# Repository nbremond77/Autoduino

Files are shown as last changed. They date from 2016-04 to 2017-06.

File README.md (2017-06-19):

# Autoduino

Arduino UNO shield to interface the I/O modules of A4 Technology // Autoduino est un bouclier pour Arduino Uno qui permet de piloter les maquettes A4 Technology utilisées pour l'enseignement de la technologie.

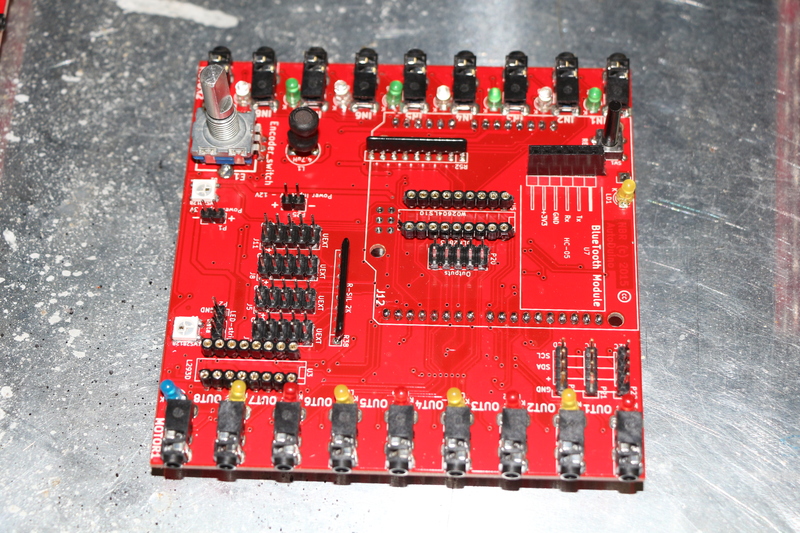
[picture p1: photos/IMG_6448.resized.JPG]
alt textAutoduino Shield


Exemples de maquettes:

http://www.a4.fr/maquette-motorisee-programmable-portail-1-battant-version-kit.html

http://www.a4.fr/banc-d-essai-eclairage-domestique-autolumi-version-kit.html

http://www.a4.fr/autoalarme-maquette-experimentale-d-un-systeme-d-alarme-kit.html

Vous trouverez sur ce site, les fichiers relatif à la carte électronique, et les développements logiciels associés.

# Introduction
Le bouclier Autoduino permet de piloter les maquettes A4 technology grâce à un Arduino UNO. Pour cela, le bouclier est équipé de 
- 16 connecteurs Jack 2.5mm permettant la connection des capteurs et actionneurs de la maquette, équipé de LED pour indiquer l'état de l'entrée ou de la sortie.
- 2 connecteurs jack 2.5mm pour deux moteurs DC,
- 2 LED RGB adressables (type WS2812B),
- 1 encodeur/push,
- quelques connecteurs supplémentaires permettant de connecter des capteurs/actionneurs plus évolués UEXT (I2C, SPI, Serial...) ou I2C pour un écran LCD (non testé) par exemple,
- 1 connecteur pour un module BlueTooth,
- 1 convertisseur Step/Up permettant d'alimenter la carte et l'Arduino avec deux piles de 1.5V, ou avec un accumulateur 3.7V.

Pour supporter le grand nombre d'entrées/sorties, il a été nécessaire d'utiliser un GPIO Expander (PCA9555). Celà implique l'utilisation d'une bibliothèque logiciel adaptée.
La programmation de l'Arduino peut se faire grâce à blockly@rDuino: http://technologiescollege.github.io/ qui inclus maintenant la bibliothèque adéquate.

A noter: Autoduino utilise des composants CMS et des composants traversants. Le cuircuit imprimé fait 100x100mm et est du type double-face.

# Note importante
Une nouvelle version de cet Autoduino est en préparation. La carte électronique sera plus simple (moins de connecteurs), et surtout, elle sera adaptée à un Arduino Due qui dispose de beaucoup plus d'entrées/sortie. Cela permettra d'éviter l'utilisation du GPIO Explander (PCA9555), ce qui simplifie grandement le logiciel.
De plus, l'Arduino Due fonctionne en 3.3V, ce qui simplifie l'utilisation de périphériques récents (Ecran tactile LCD...). Les moteurs resteront connectés au 5V.
Enfin, c'est un processeur 32 bits beaucoup plus performant que celui de l'Arduino Uno;

De plus, j'ai prévu quelques amélioration:
- Ajout de connecteurs Grove en plus des connecteurs jack 2.5mm, pour permettre une utilisation beaucoup plus polyvalente,
- Possibilité de connecter le module Bluetooth sur un RX/TX différent de celui connecté à l'USB,
- Ajouter une interface permettant de connecter un écran tactile LCD de 2.8 pouces.

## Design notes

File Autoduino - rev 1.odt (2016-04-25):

Autoduino

# Description

Autoduino est un module (carte électronique et boîtier) développé pour piloter les maquettes didactiques de type alarme de maison, éclairage, portail, etc.

Ce module basé sur un Arduino peut être programmé par l'enseignant ou les élèves, soit dans un environnement de développement utilisant un langage proche du langage C, soir graphiquement dans Drakon (programme multi-plateforme de programmation graphique).

Ce module Autoduino se connecte à des petites cartes d'interface (entrée bouton poussoir, télécommande infra rouge, contact fin de course, … et sorties Led, moteur, buzzer, …) qui sont situées sur les maquettes que l'on souhaite animer.

# Autres modules disponibles sur le marché

L'Autoduino est équivalent aux modules suivants de la société A4 technologie :

- Autoprog (environ 180 Euros monté, 100 Euros en kit)
- Autoprog Uno (environ 230 Euros monté)

Par rapport à ces modules, on note les avantages suivants :

- Moins cher si les achats sont optimisés (environ 70 Euros de composants si réalisés en 10 exemplaires),
- Équipe en standard d'un écran LCD et d'un bouton rotatif ce qui facilite le débogage des programmes,
- Équipé d'une interface moteur intégrée,
- Equipé d'une interface radio de type Bluetooth permettant à plusieurs module de dialoguer entre eux,
- Basé sur un Arduino (architecture/carte très connue est appréciée dans le milieu éducatif, facile à programmer) qui dispose d'une puissance de calcul très supérieure au PicAxe qui équipe l'Autoprog. L'Autoprog Uno est quant à lui équipé d'un Arduino.
- Compatible avec d'autres carte à micro-contrôleurs, par exemple STM32/Nucleo qui dispose d'un micro-contrôleur 32 bits tournant à 100MHz offrant ainsi une puissance de calcul sans commune mesure.

# Applications

Les applications envisagées sont les suivantes :

- Pilotage des maquettes A4 Technologie : Alarme maison, éclairage maison, portail, plate-forme élévatrice…
- Pilotage de mini-robots, ou de véhicules télécommandés ou autonomes,
- Système de mesure automatisée pour le laboratoire de physique.

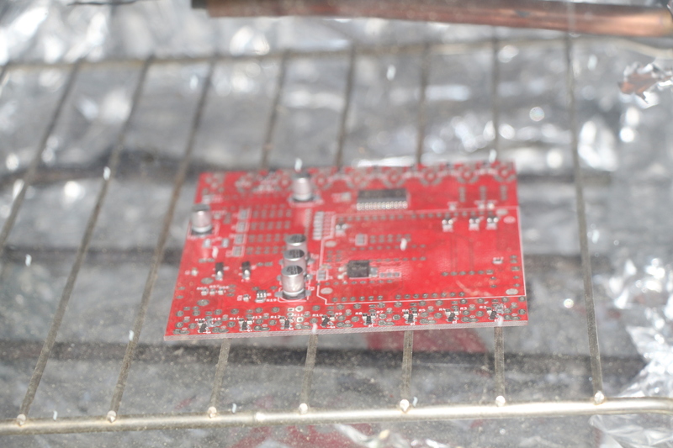
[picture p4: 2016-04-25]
photos/IMG_6421.resized.JPG

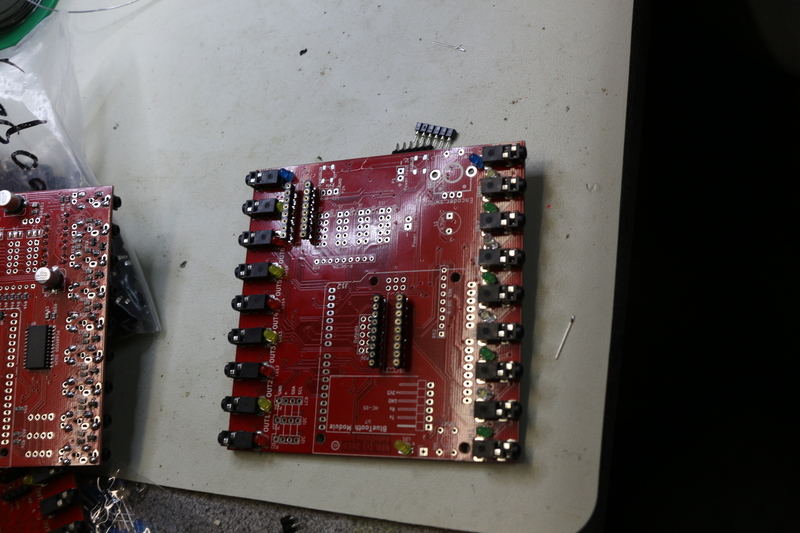
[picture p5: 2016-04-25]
photos/IMG_6434.resized.JPG

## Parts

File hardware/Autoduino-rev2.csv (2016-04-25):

Reference | Value | Footprint | Datasheet
SW1 | Push1 | FreeTtronics:SW_PUSHBUTTON_PTH
J3 | UEXT | Pin_Headers:Pin_Header_Straight_2x05
J5 | UEXT | Pin_Headers:Pin_Header_Straight_2x05
J12 | Nucleo/Arduino Board header | FreeTtronics:ARDUINO_SHIELD
U2 | MCP1640t-i/chy | w_smd_trans:sot23-6
C4 | 220uF/16V | Capacitors_SMD:c_elec_8x10
C2 | 220uF/16V | Capacitors_SMD:c_elec_8x10
R19 | 976k 1% | Resistors_SMD:R_0805
R20 | 309k 1% | Resistors_SMD:R_0805
L1 | 4.7uH | Inductors:INDUCTOR_V
J2 | V_select | br_pretty:Select
J4 | V_select | br_pretty:Select
U6 | 24xx512 EEPROM - NC | w_smd_dil:so-8
P1 | Power Input 3V | Pin_Headers:Pin_Header_Straight_1x02
R52 | R-SIL 10K | Discret:r_pack8
J8 | UEXT | Pin_Headers:Pin_Header_Straight_2x05
J6 | V_select | br_pretty:Select
U5 | ULN2803 - NC | Sockets_DIP:DIP-18__300
P20 | Outputs - NC | Pin_Headers:Pin_Header_Straight_2x05
Q18 | BSS138 | FreeTtronics:SOT23_FET
LD2 | LED Green | LEDs:LED-3MM
U4 | PCA9555D SO24 | Housings_SOIC:SOIC-24_7.5x15.4mm_Pitch1.27mm
P23 | LCD | Pin_Headers:Pin_Header_Straight_1x04
D1 | DIODE | Diodes_SMD:Diode-MiniMELF_Handsoldering
E1 | Encoder_switch | w_misc_comp:encoder_alps-ec12d
C9 | 100n | Capacitors_SMD:C_0805
C10 | 100n | Capacitors_SMD:C_0805
U3 | L293D | Sockets_DIP:DIP-16__300
D2 | WS2812B | FreeTtronics:WS2812B
D3 | WS2812B | FreeTtronics:WS2812B
U7 | HC-05 | Pin_Headers:Pin_Header_Angled_1x06
R1 | 1k | Resistors_SMD:R_0805
C8 | 220uF/16V | Capacitors_SMD:c_elec_8x10
J1 | V_select | br_pretty:Select
Q19 | BSS138 | FreeTtronics:SOT23_FET
Q20 | BSS138 | FreeTtronics:SOT23_FET
R59 | 220R | Resistors_SMD:R_0805
P24 | LED-strip | Pin_Headers:Pin_Header_Straight_1x03
C11 | 220uF/16V | Capacitors_SMD:c_elec_8x10
Q1 | BSS138 | FreeTtronics:SOT23_FET
R44 | 1k | Resistors_SMD:R_0805
R45 | 1k | Resistors_SMD:R_0805
R46 | 1k | Resistors_SMD:R_0805
R57 | 10k | Resistors_SMD:R_0805
R58 | 10k | Resistors_SMD:R_0805
R60 | 10k | Resistors_SMD:R_0805
R47 | 1k | Resistors_SMD:R_0805
R48 | 1k | Resistors_SMD:R_0805
C6 | 100n | Capacitors_SMD:C_0805
U1 | LD29150DT33R | FreeTtronics:DPAK
C3 | 220uF/16V | Capacitors_SMD:c_elec_8x10
C1 | 100n | Capacitors_SMD:C_0805
J11 | UEXT | Pin_Headers:Pin_Header_Straight_2x05
J10 | V_select | br_pretty:Select
R49 | 1k | Resistors_SMD:R_0805
R50 | 1k | Resistors_SMD:R_0805
R56 | 1k | Resistors_SMD:R_0805
R17 | 220R | Resistors_SMD:R_0805
LD1 | LED Yellow | LEDs:LED-3MM
P22 | I2C | Pin_Headers:Pin_Header_Straight_1x04
P21 | I2C | Pin_Headers:Pin_Header_Straight_1x04
J7 | V_select | br_pretty:Select
R38 | R-SIL 2K | Discret:r_pack8
R41 | 10k | Resistors_SMD:R_0805
R42 | 10k | Resistors_SMD:R_0805
R43 | 10k | Resistors_SMD:R_0805
R53 | 10k | Resistors_SMD:R_0805
R54 | 10k | Resistors_SMD:R_0805
R55 | 10k | Resistors_SMD:R_0805
R37 | 1k | Resistors_SMD:R_0805
R39 | 1k | Resistors_SMD:R_0805
LD18 | LED Yellow | LEDs:LED-3MM
LD19 | LED Yellow | LEDs:LED-3MM
J9 | V_select | br_pretty:Select
Q17 | BSS138 | FreeTtronics:SOT23_FET
R51 | 10k | Resistors_SMD:R_0805
R40 | 10k | Resistors_SMD:R_0805
P9 | IN8 | pretty:PC-208B-Jack2.5_Stereo
LD10 | LED Red | LEDs:LED-3MM
R21 | 1k | Resistors_SMD:R_0805
Q9 | BSS138 | FreeTtronics:SOT23_FET
P17 | OUT8 | pretty:PC-208B-Jack2.5_Stereo
LD3 | LED Green | LEDs:LED-3MM
R3 | 1k | Resistors_SMD:R_0805
Q2 | BSS138 | FreeTtronics:SOT23_FET
P2 | IN1 | pretty:PC-208B-Jack2.5_Stereo
LD11 | LED Red | LEDs:LED-3MM
R23 | 1k | Resistors_SMD:R_0805
Q10 | BSS138 | FreeTtronics:SOT23_FET
P10 | OUT1 | pretty:PC-208B-Jack2.5_Stereo
LD4 | LED Green | LEDs:LED-3MM
R5 | 1k | Resistors_SMD:R_0805
Q3 | BSS138 | FreeTtronics:SOT23_FET
P3 | IN2 | pretty:PC-208B-Jack2.5_Stereo
LD12 | LED Red | LEDs:LED-3MM
R25 | 1k | Resistors_SMD:R_0805
Q11 | BSS138 | FreeTtronics:SOT23_FET
P11 | OUT2 | pretty:PC-208B-Jack2.5_Stereo
LD5 | LED Green | LEDs:LED-3MM
R7 | 1k | Resistors_SMD:R_0805
Q4 | BSS138 | FreeTtronics:SOT23_FET
P4 | IN3 | pretty:PC-208B-Jack2.5_Stereo
LD13 | LED Red | LEDs:LED-3MM
R27 | 1k | Resistors_SMD:R_0805
Q12 | BSS138 | FreeTtronics:SOT23_FET
P12 | OUT3 | pretty:PC-208B-Jack2.5_Stereo
LD6 | LED Green | LEDs:LED-3MM
R9 | 1k | Resistors_SMD:R_0805
Q5 | BSS138 | FreeTtronics:SOT23_FET
P5 | IN4 | pretty:PC-208B-Jack2.5_Stereo
LD14 | LED Red | LEDs:LED-3MM
R29 | 1k | Resistors_SMD:R_0805
Q13 | BSS138 | FreeTtronics:SOT23_FET
P13 | OUT4 | pretty:PC-208B-Jack2.5_Stereo
LD7 | LED Green | LEDs:LED-3MM
R11 | 1k | Resistors_SMD:R_0805
Q6 | BSS138 | FreeTtronics:SOT23_FET
P6 | IN5 | pretty:PC-208B-Jack2.5_Stereo
LD15 | LED Red | LEDs:LED-3MM
R31 | 1k | Resistors_SMD:R_0805
Q14 | BSS138 | FreeTtronics:SOT23_FET
P14 | OUT5 | pretty:PC-208B-Jack2.5_Stereo
LD8 | LED Green | LEDs:LED-3MM
R13 | 1k | Resistors_SMD:R_0805
Q7 | BSS138 | FreeTtronics:SOT23_FET
P7 | IN6 | pretty:PC-208B-Jack2.5_Stereo
LD16 | LED Red | LEDs:LED-3MM
R33 | 1k | Resistors_SMD:R_0805
Q15 | BSS138 | FreeTtronics:SOT23_FET
P15 | OUT6 | pretty:PC-208B-Jack2.5_Stereo
LD9 | LED Green | LEDs:LED-3MM
R15 | 1k | Resistors_SMD:R_0805
Q8 | BSS138 | FreeTtronics:SOT23_FET
P8 | IN7 | pretty:PC-208B-Jack2.5_Stereo
LD17 | LED Red | LEDs:LED-3MM
R35 | 1k | Resistors_SMD:R_0805
Q16 | BSS138 | FreeTtronics:SOT23_FET
P16 | OUT7 | pretty:PC-208B-Jack2.5_Stereo
P18 | MOTOR1 | pretty:PC-208B-Jack2.5_Stereo
P19 | MOTOR2 | pretty:PC-208B-Jack2.5_Stereo
P25 | Power Input 7V - 12V | Pin_Headers:Pin_Header_Straight_1x02
D4 | DIODE | Diodes_SMD:Diode-MiniMELF_Handsoldering
R2 | 220R | Resistors_SMD:R_0805
R4 | 220R | Resistors_SMD:R_0805
R6 | 220R | Resistors_SMD:R_0805
R8 | 220R | Resistors_SMD:R_0805
R10 | 220R | Resistors_SMD:R_0805
R12 | 220R | Resistors_SMD:R_0805
R14 | 220R | Resistors_SMD:R_0805
R16 | 220R | Resistors_SMD:R_0805
R34 | 220R | Resistors_SMD:R_0805
R32 | 220R | Resistors_SMD:R_0805
R30 | 220R | Resistors_SMD:R_0805
R28 | 220R | Resistors_SMD:R_0805
R26 | 220R | Resistors_SMD:R_0805
R24 | 220R | Resistors_SMD:R_0805
R22 | 220R | Resistors_SMD:R_0805
R18 | 220R | Resistors_SMD:R_0805

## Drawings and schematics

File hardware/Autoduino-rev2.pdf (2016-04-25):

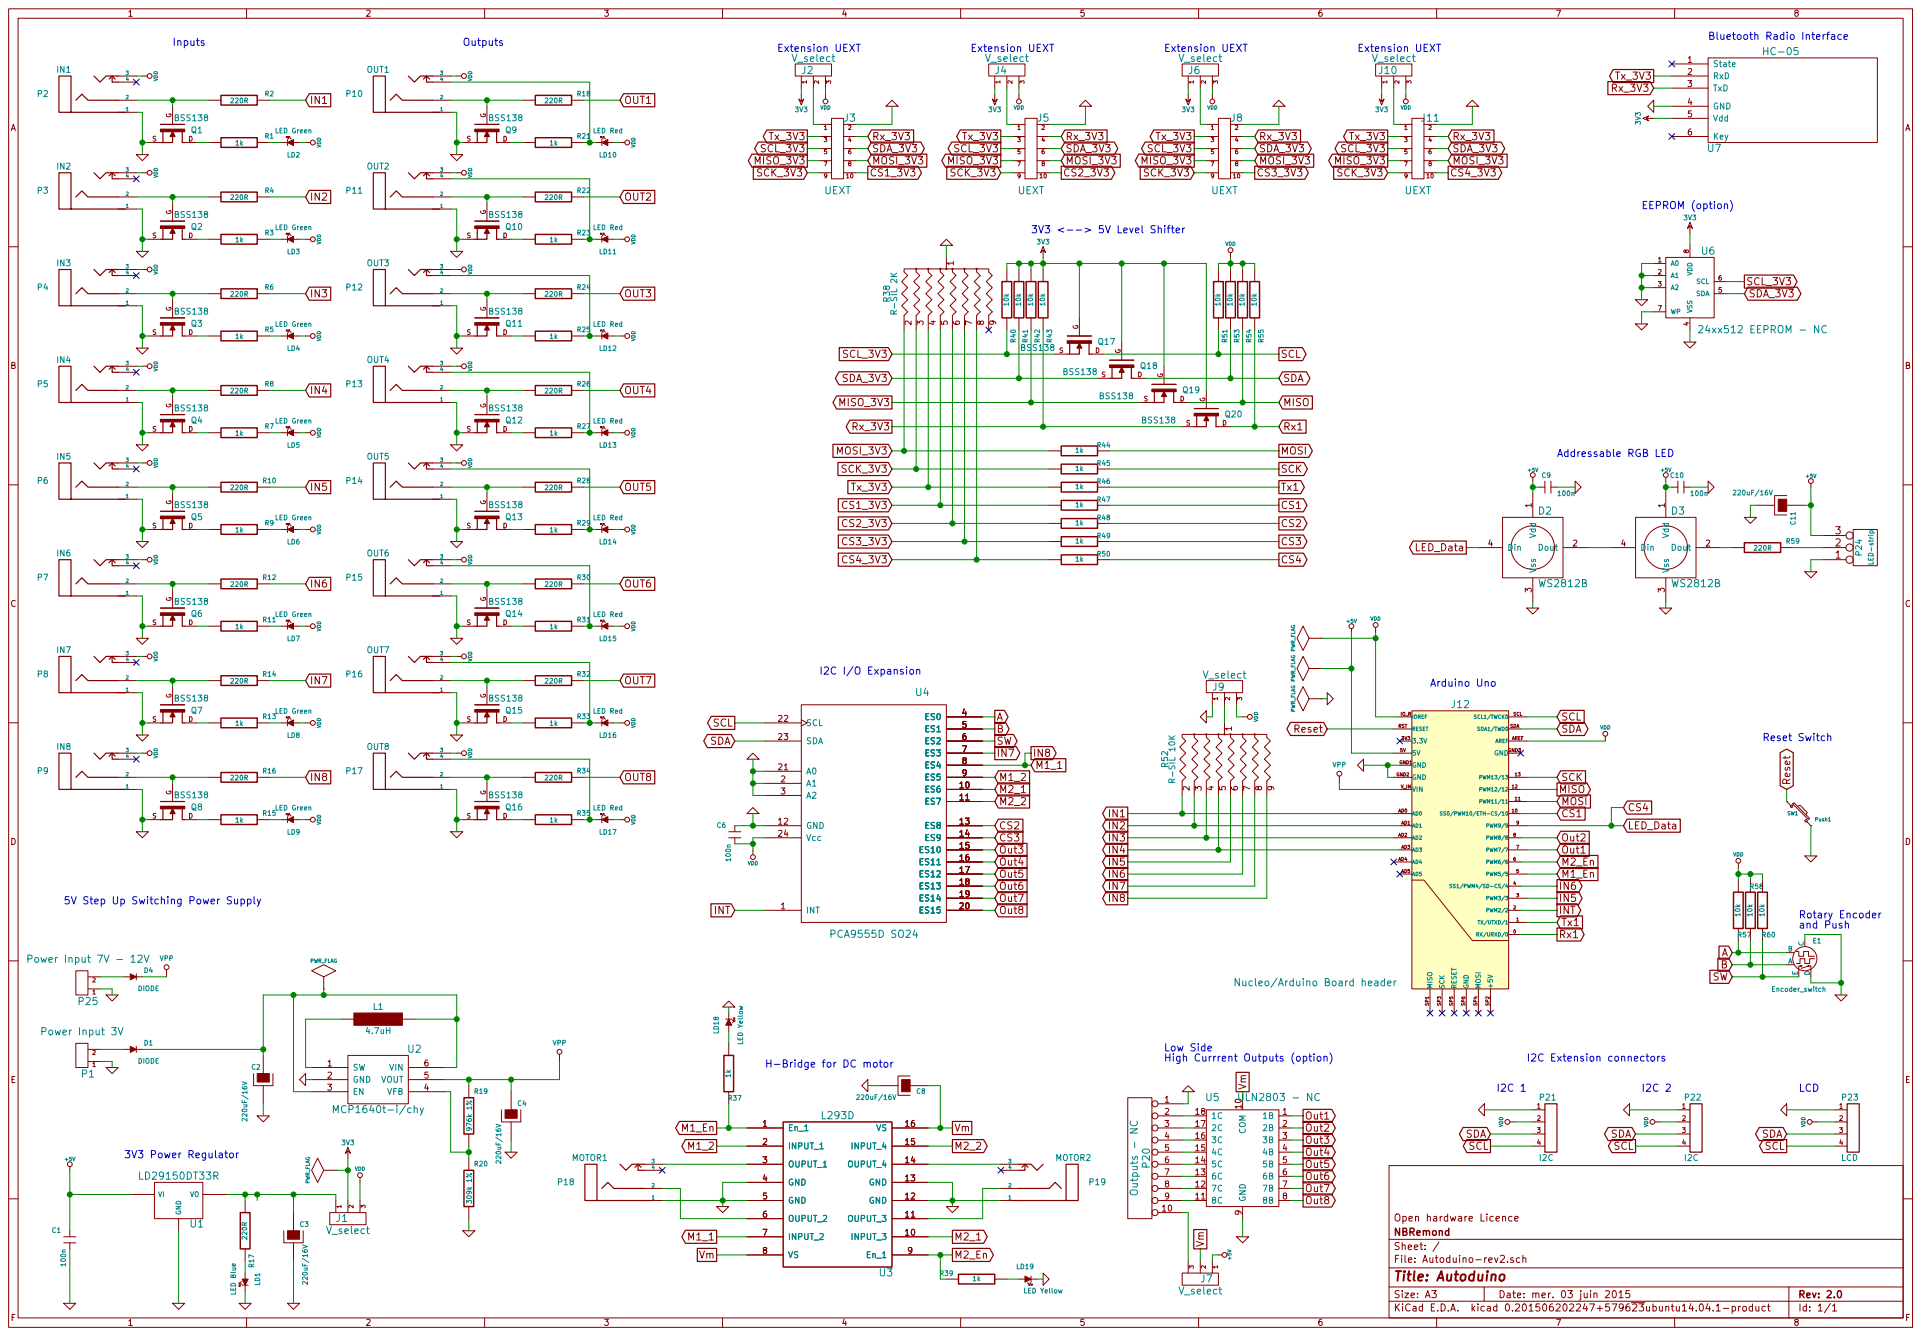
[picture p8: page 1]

1 Dout 2 Vss 3 Din 4 D2WS2812B Vdd

Rotary Encoder and Push Reset Switch

5V Step Up Switching Power Supply

Low Side
High Currrent Outputs (option)

H-Bridge for DC motor

File: Autoduino-rev2.sch Sheet: / NBRemond Open hardware Licence

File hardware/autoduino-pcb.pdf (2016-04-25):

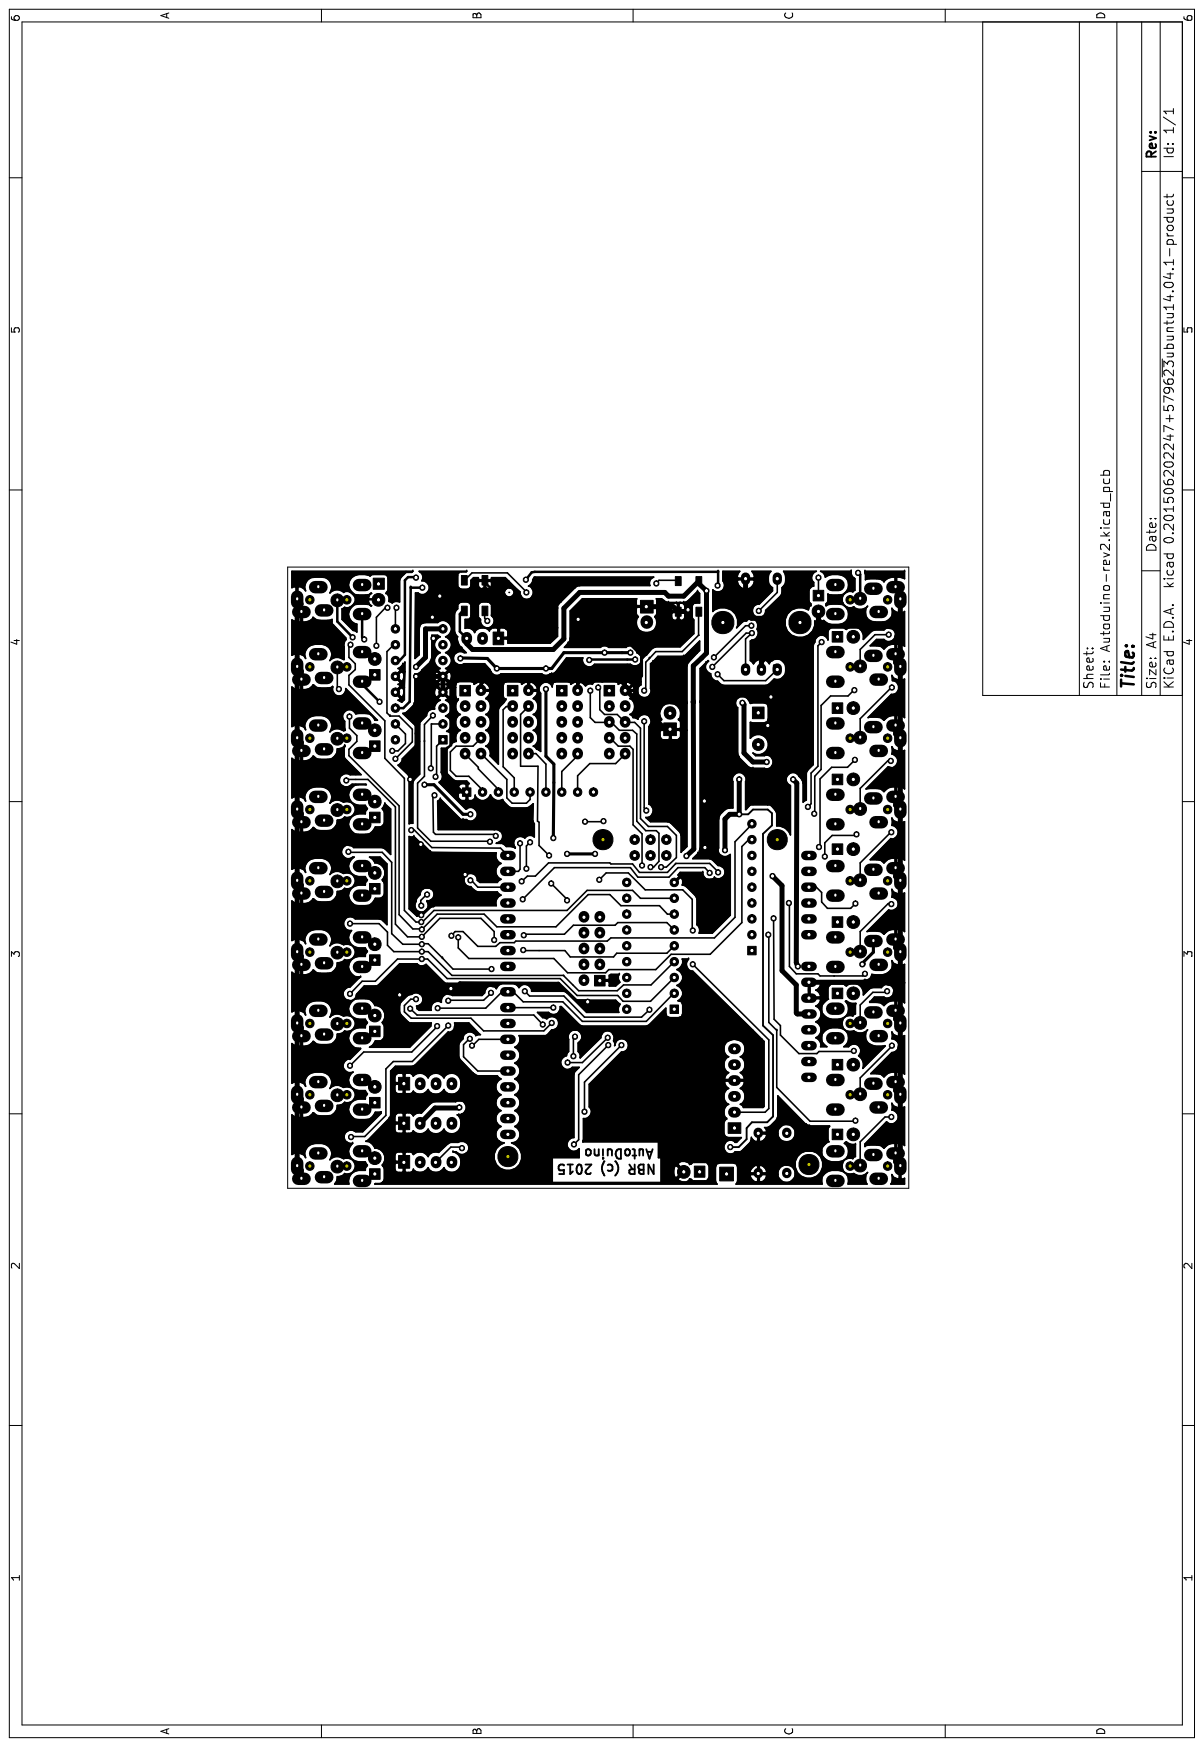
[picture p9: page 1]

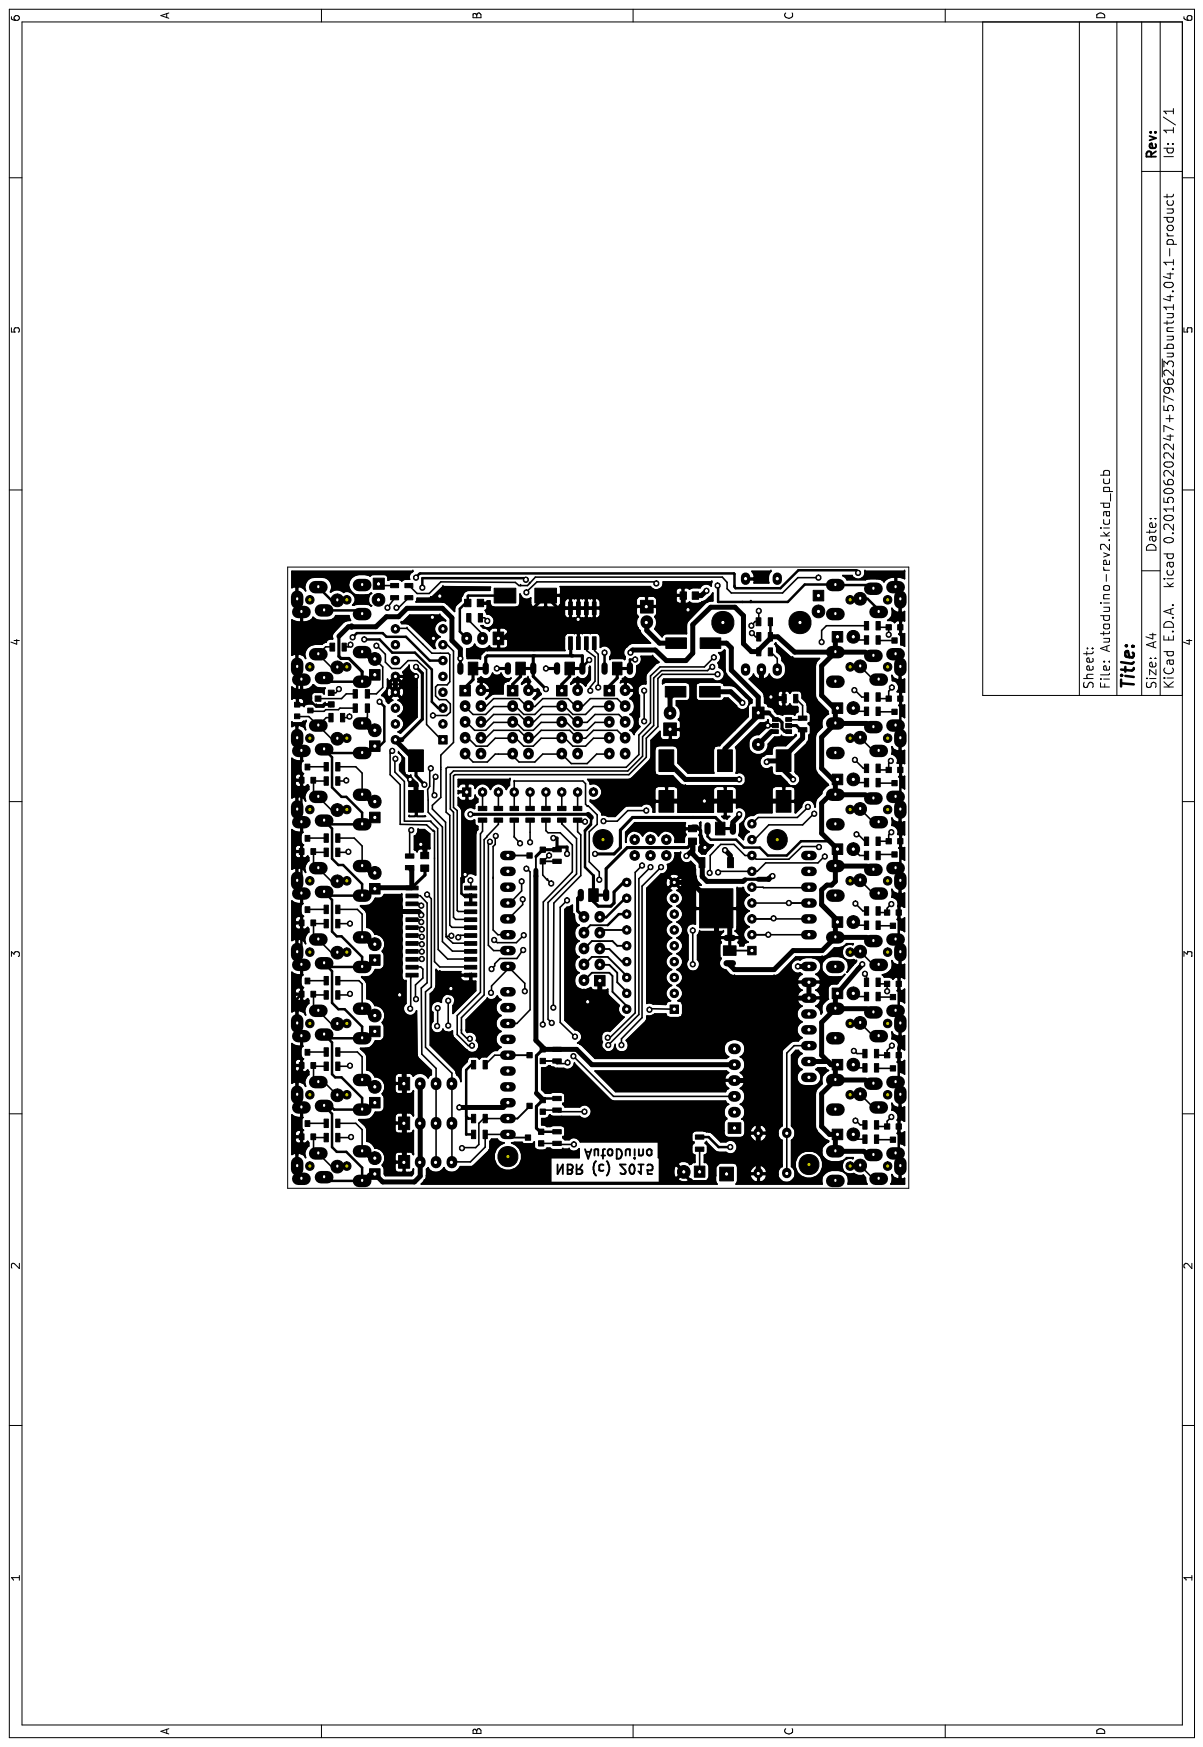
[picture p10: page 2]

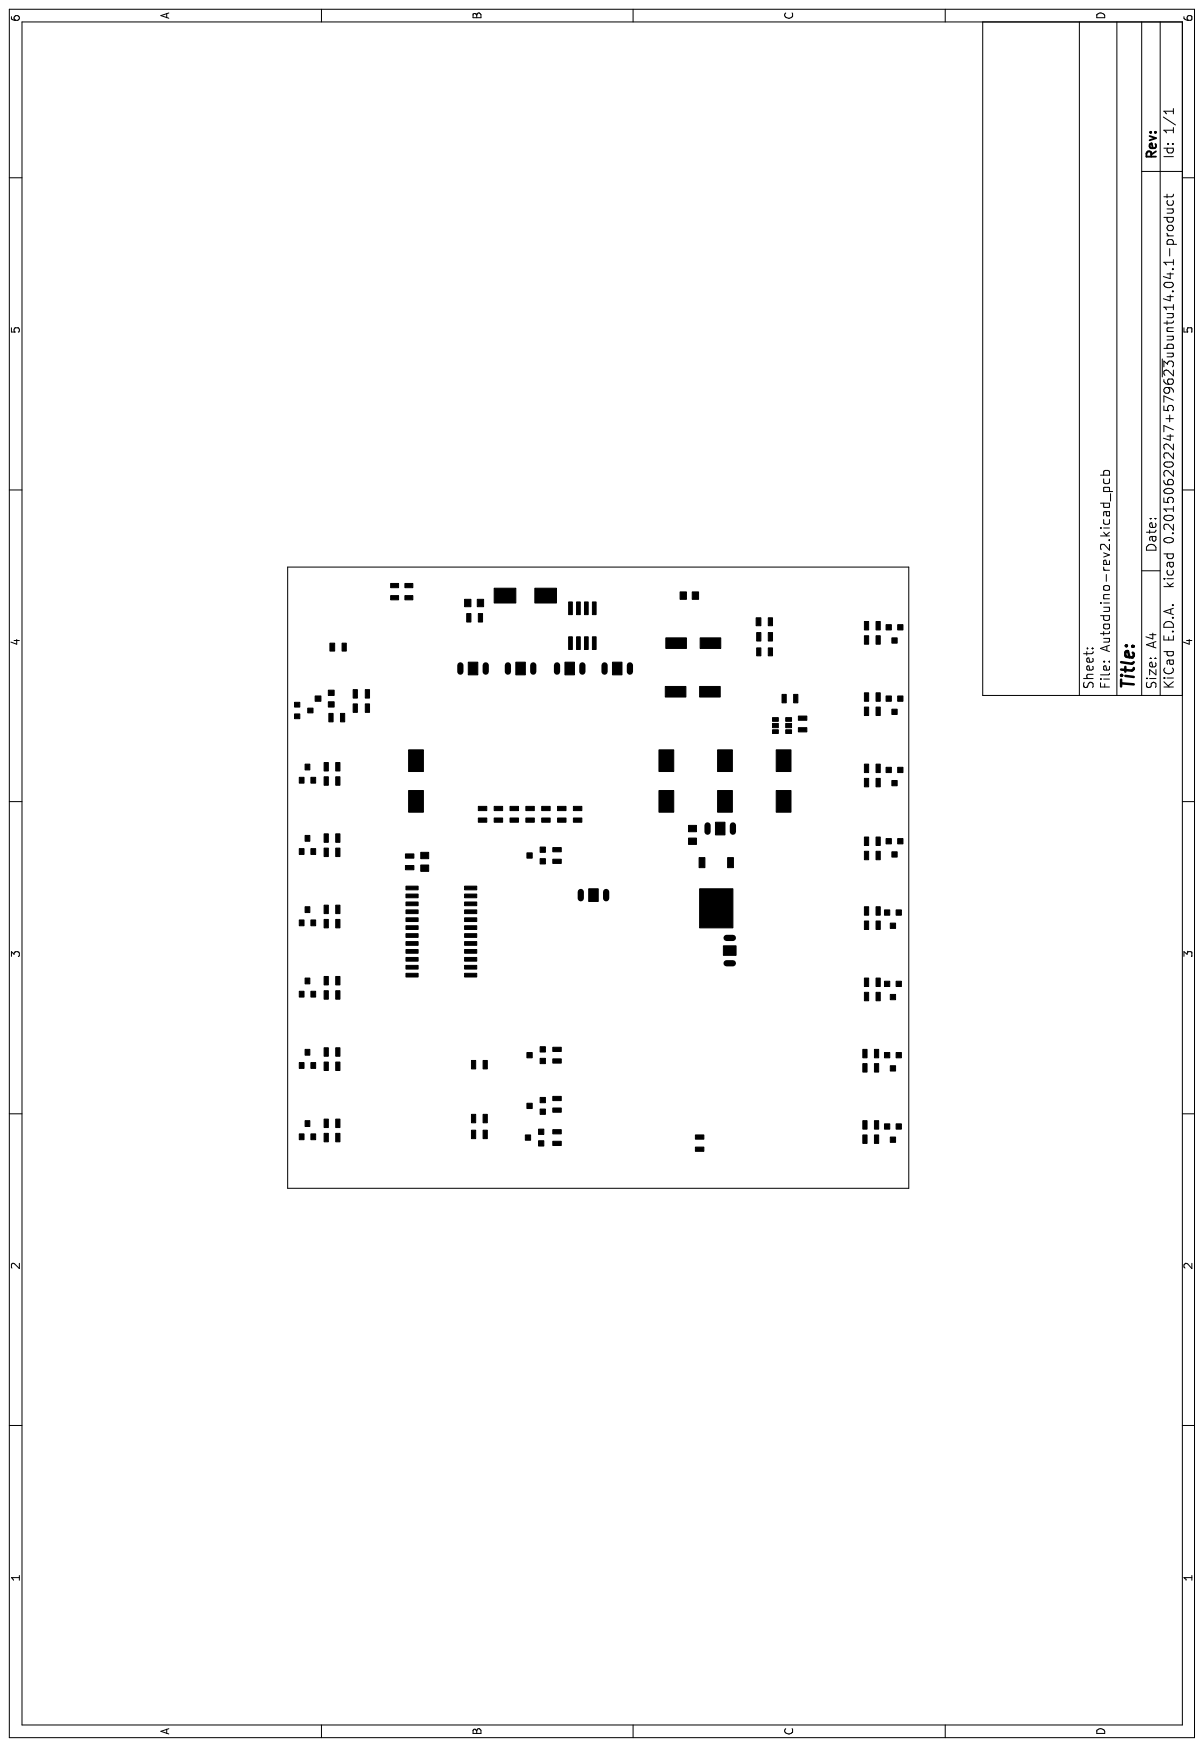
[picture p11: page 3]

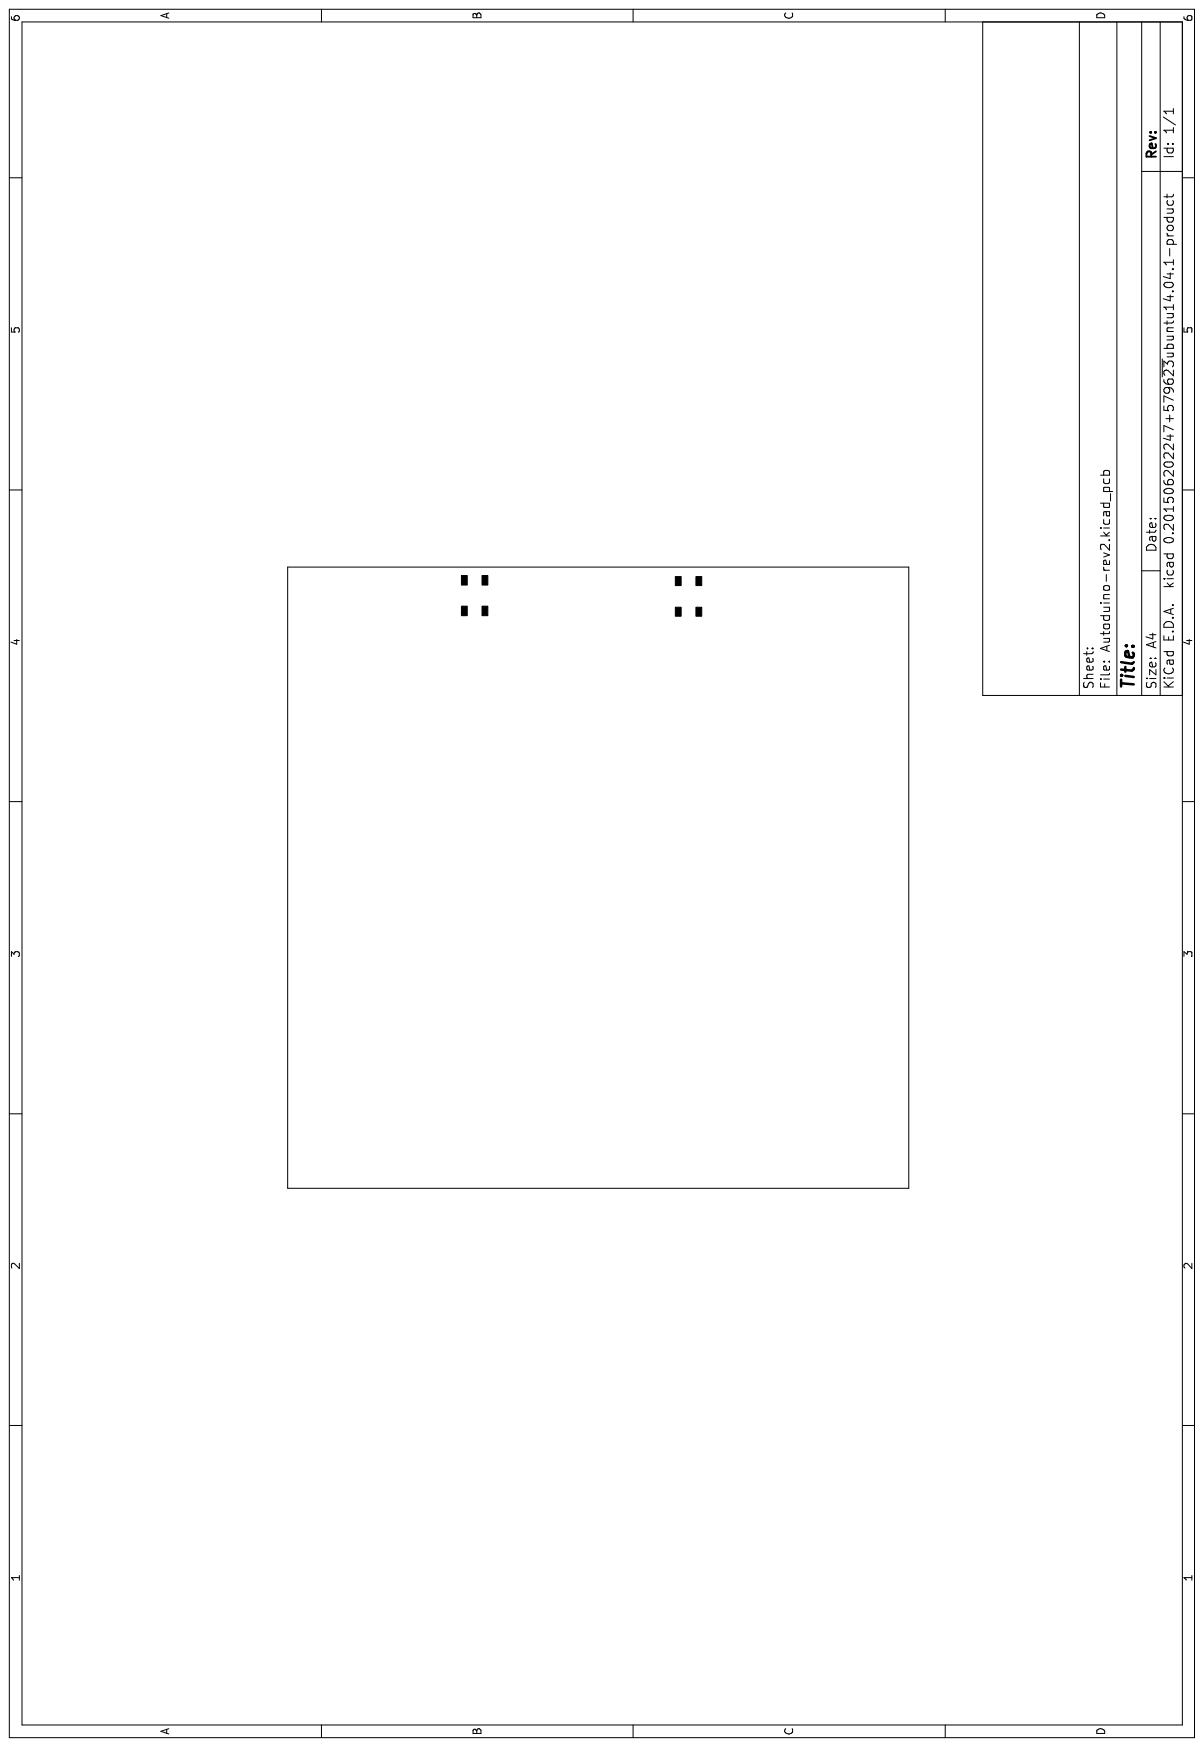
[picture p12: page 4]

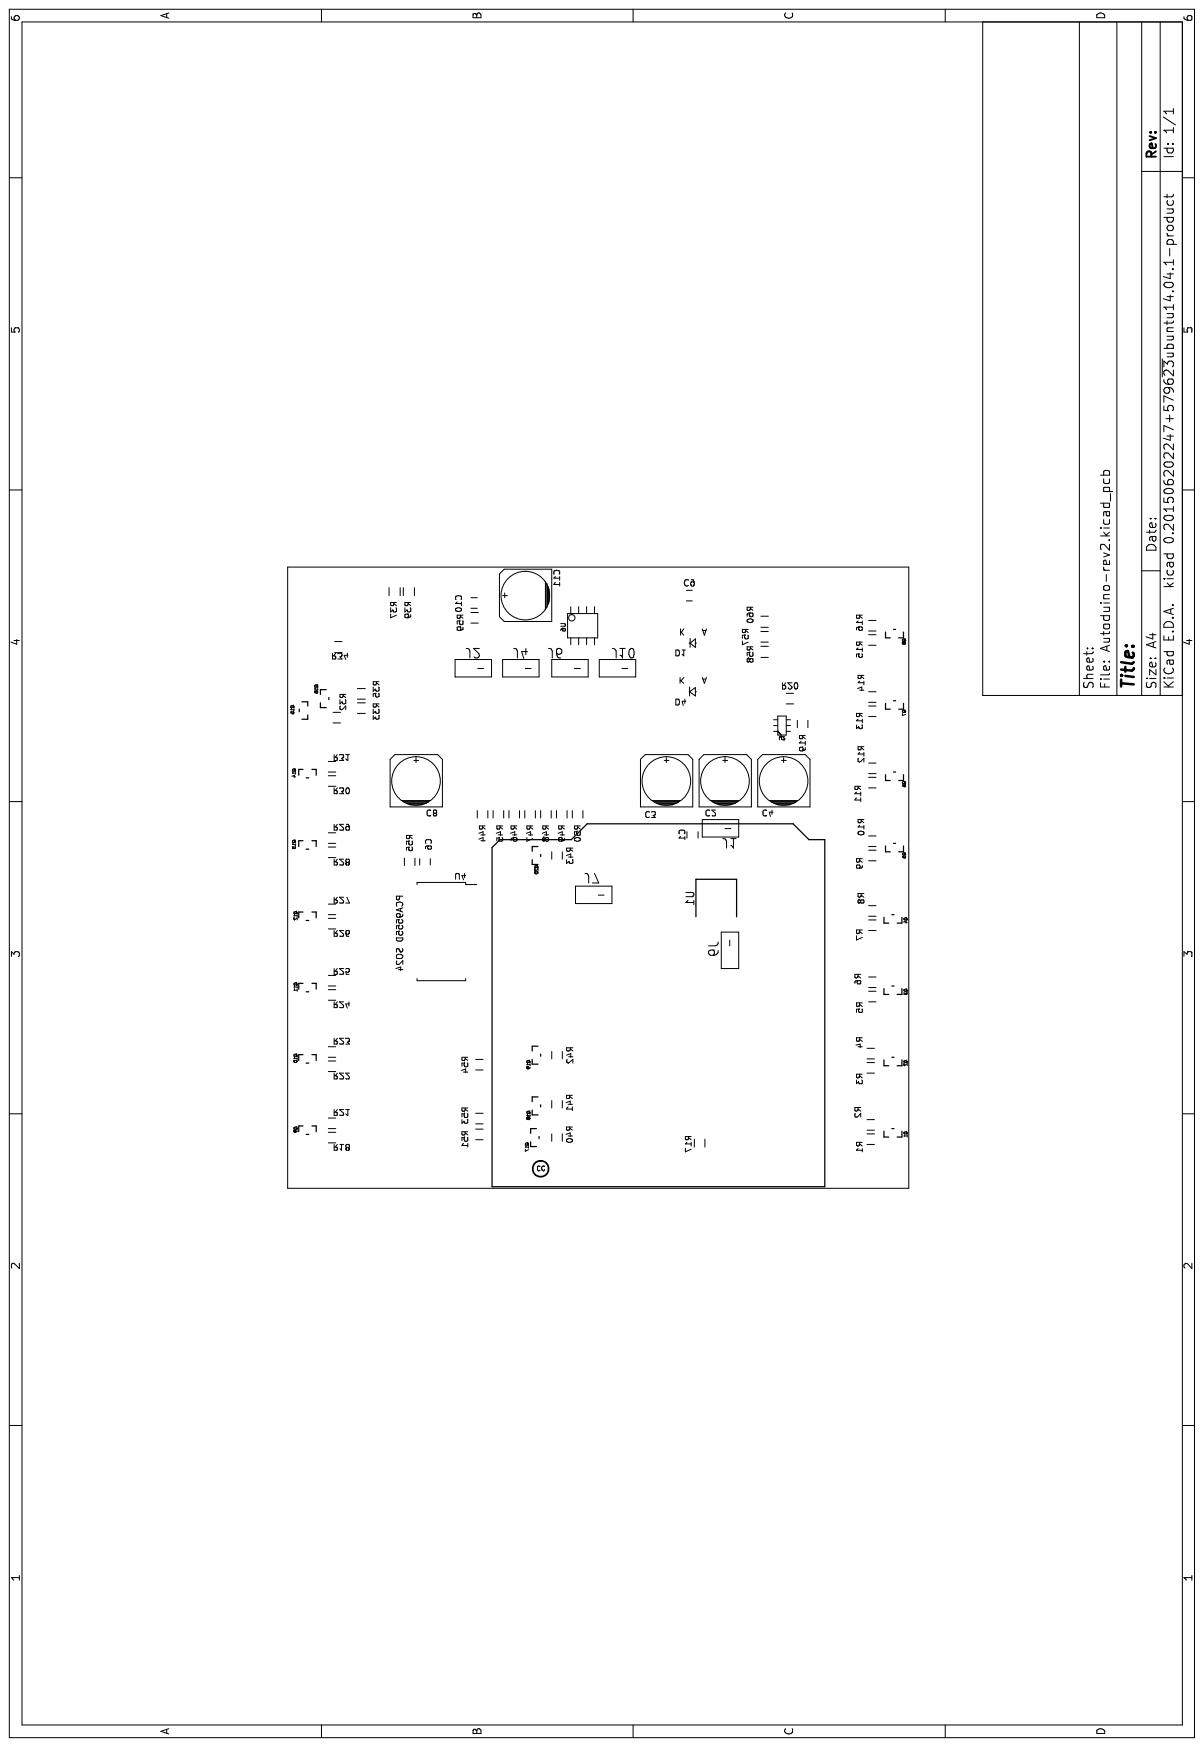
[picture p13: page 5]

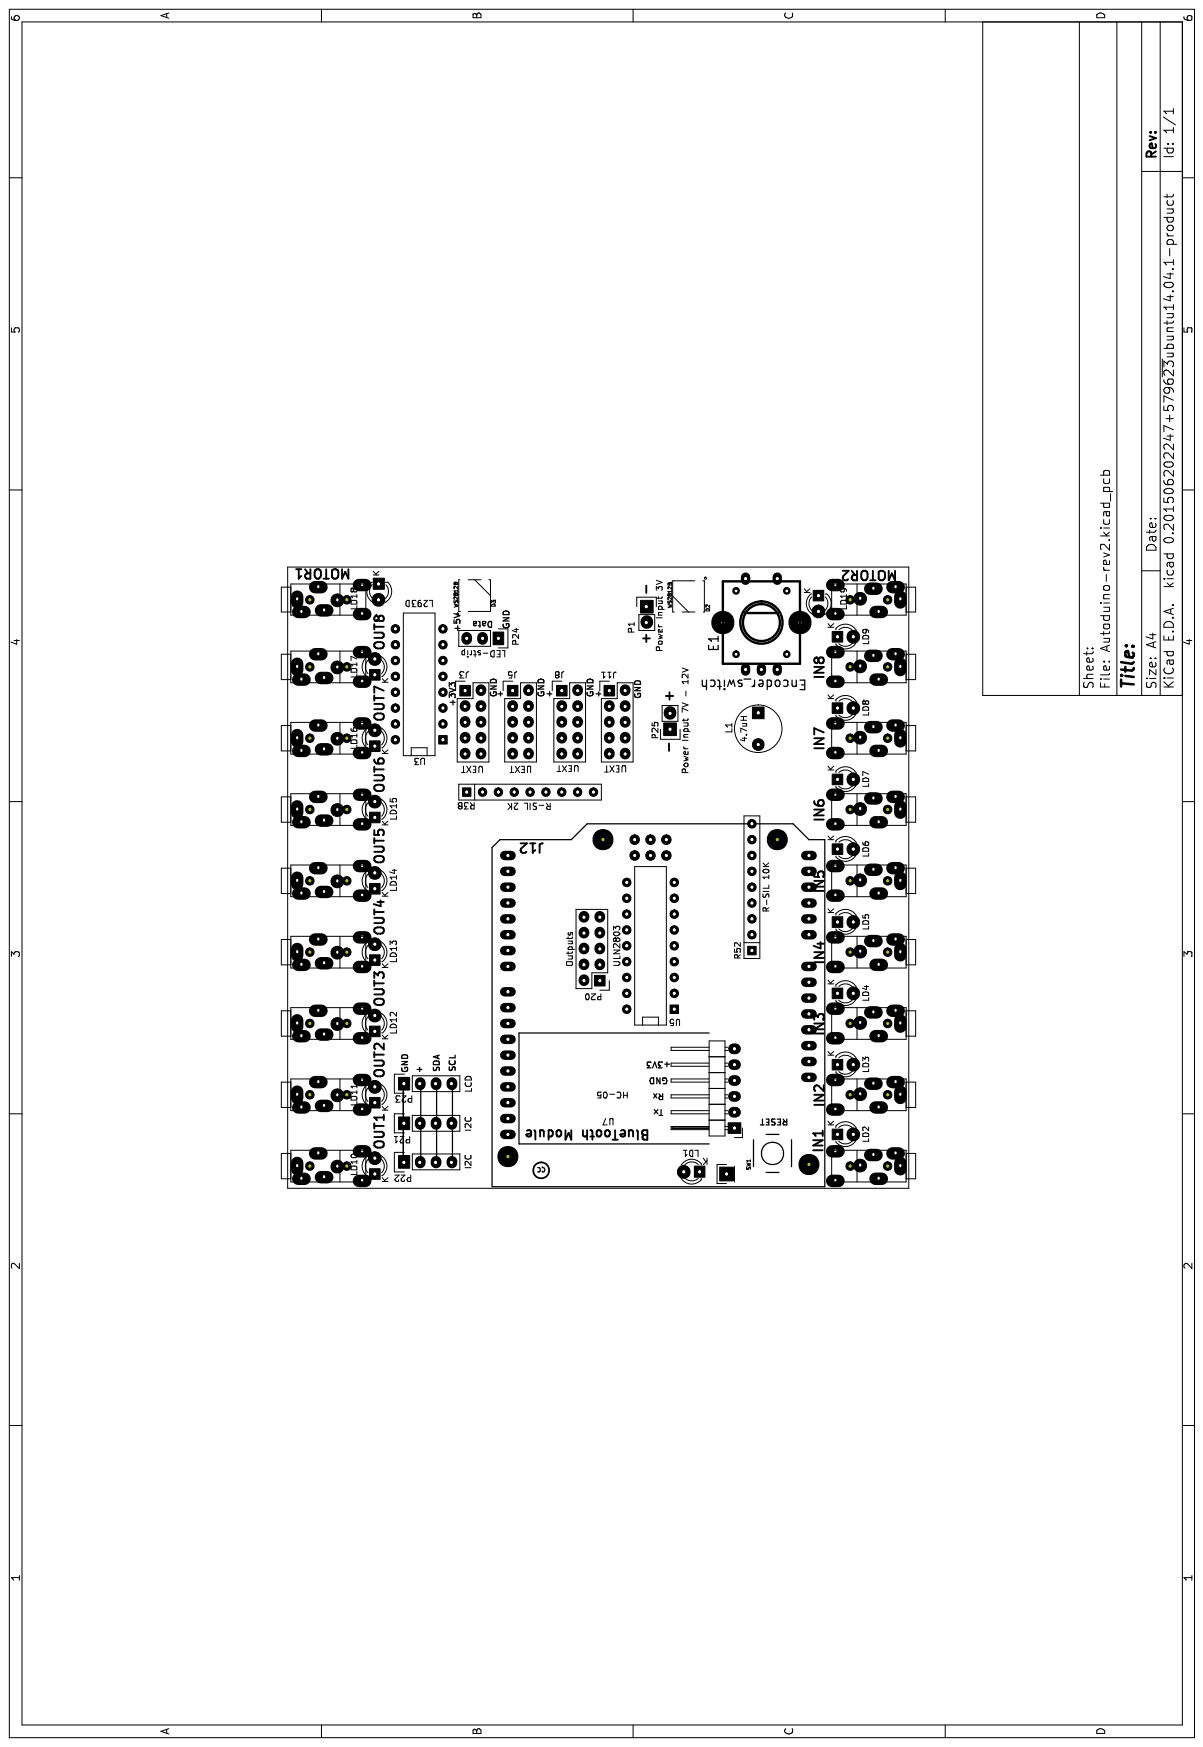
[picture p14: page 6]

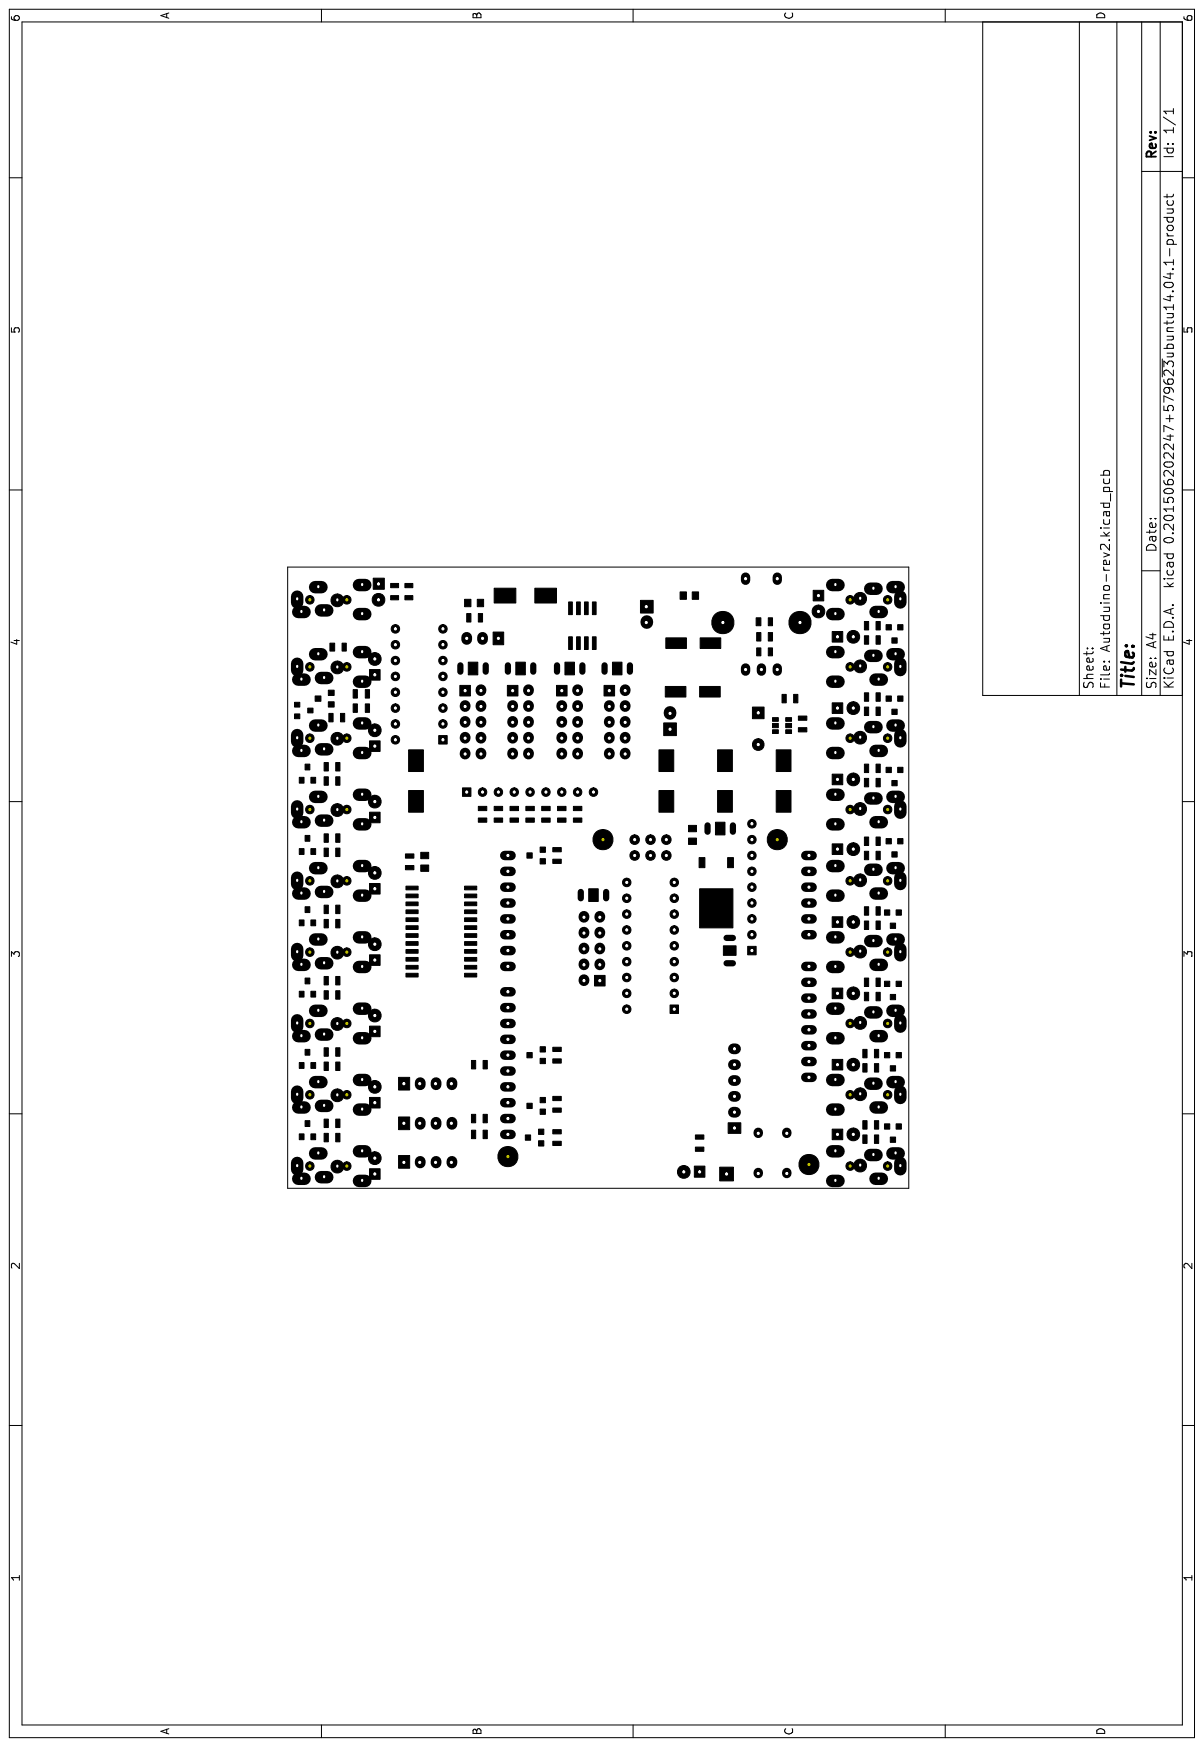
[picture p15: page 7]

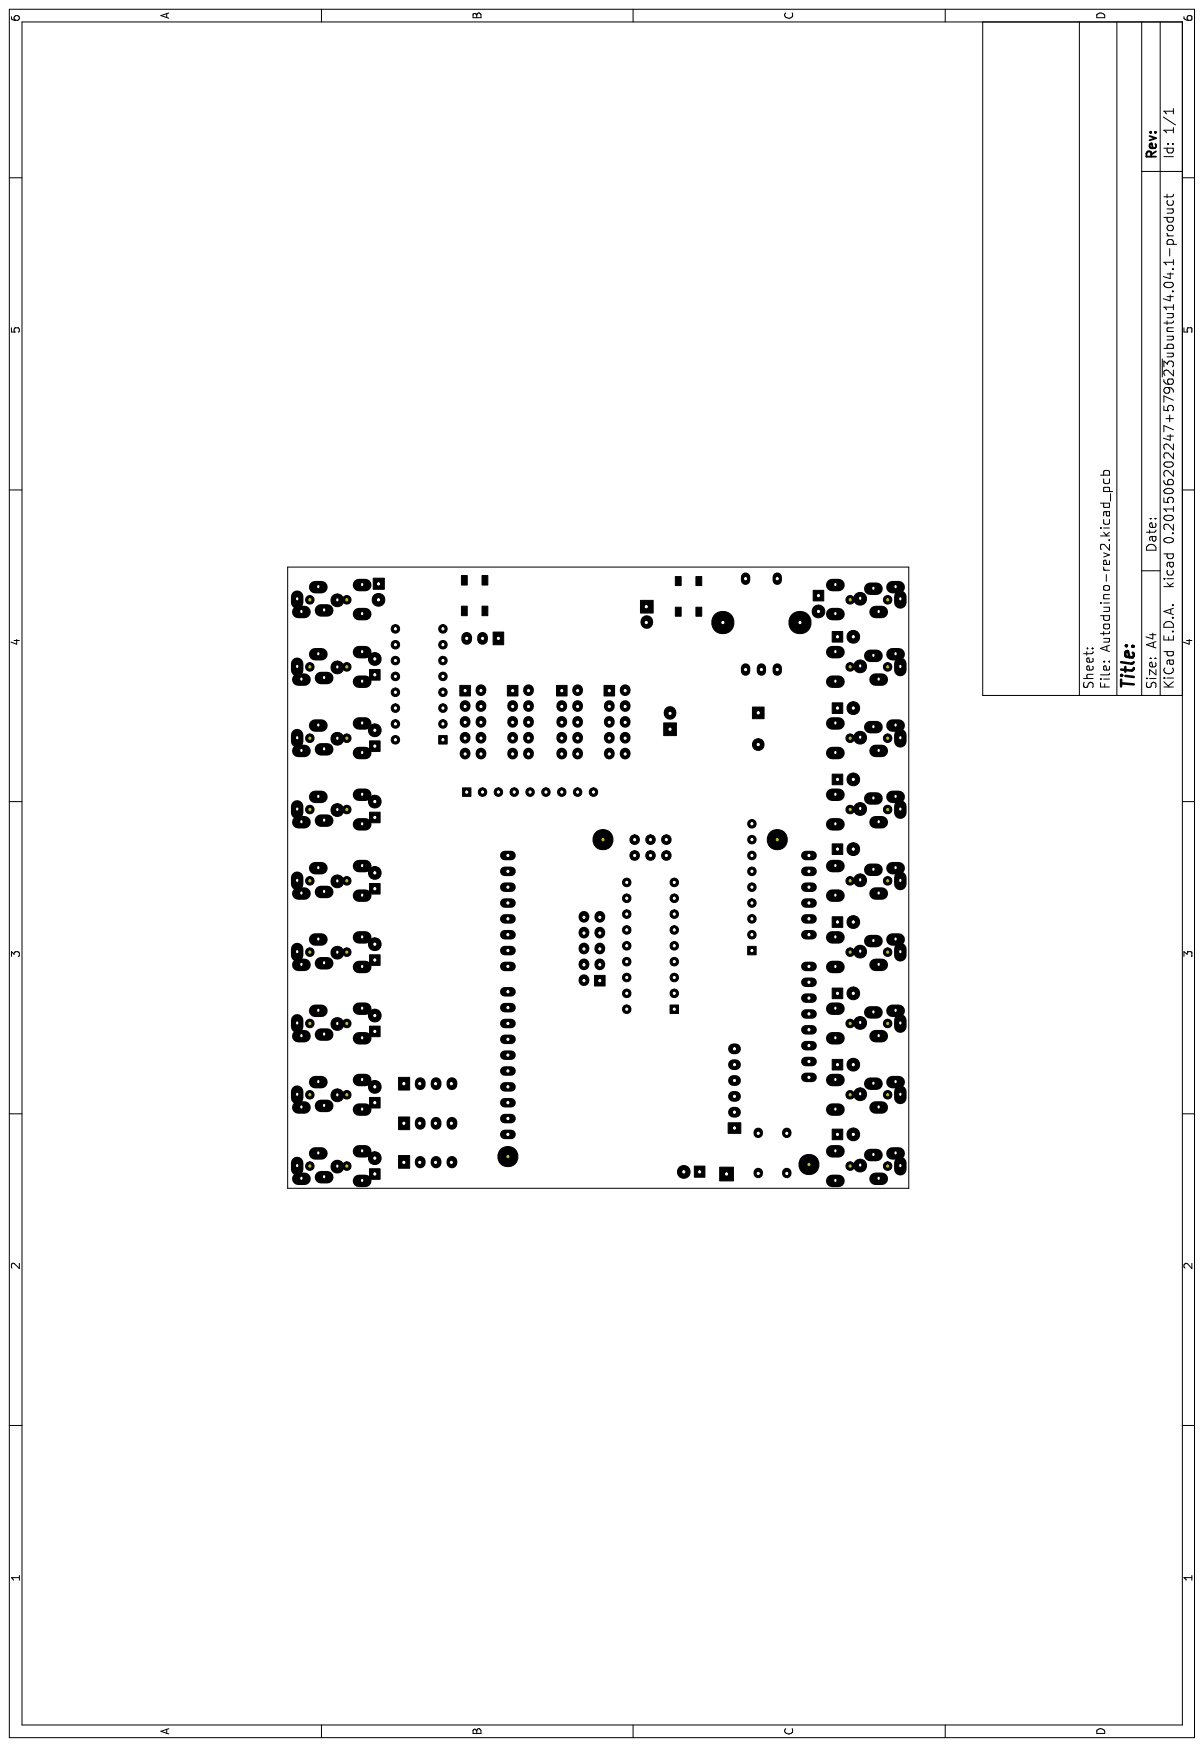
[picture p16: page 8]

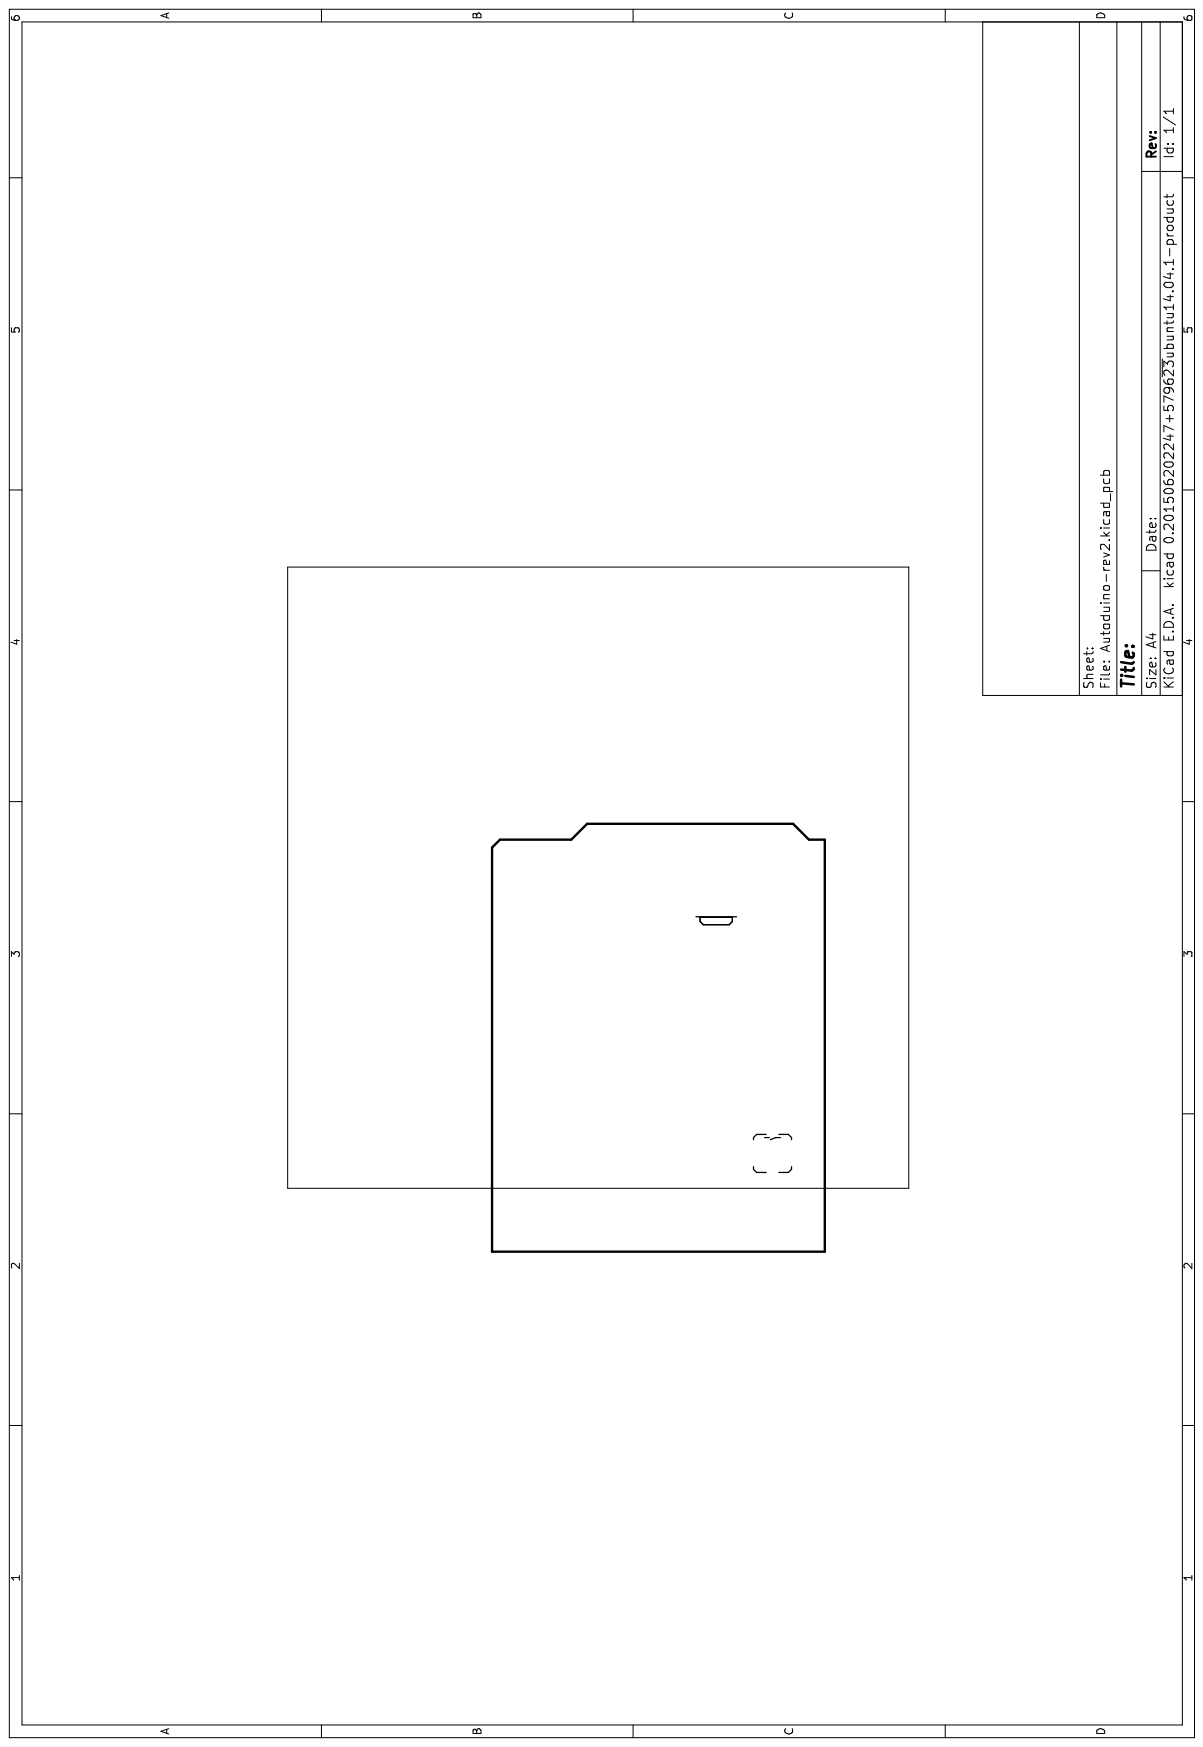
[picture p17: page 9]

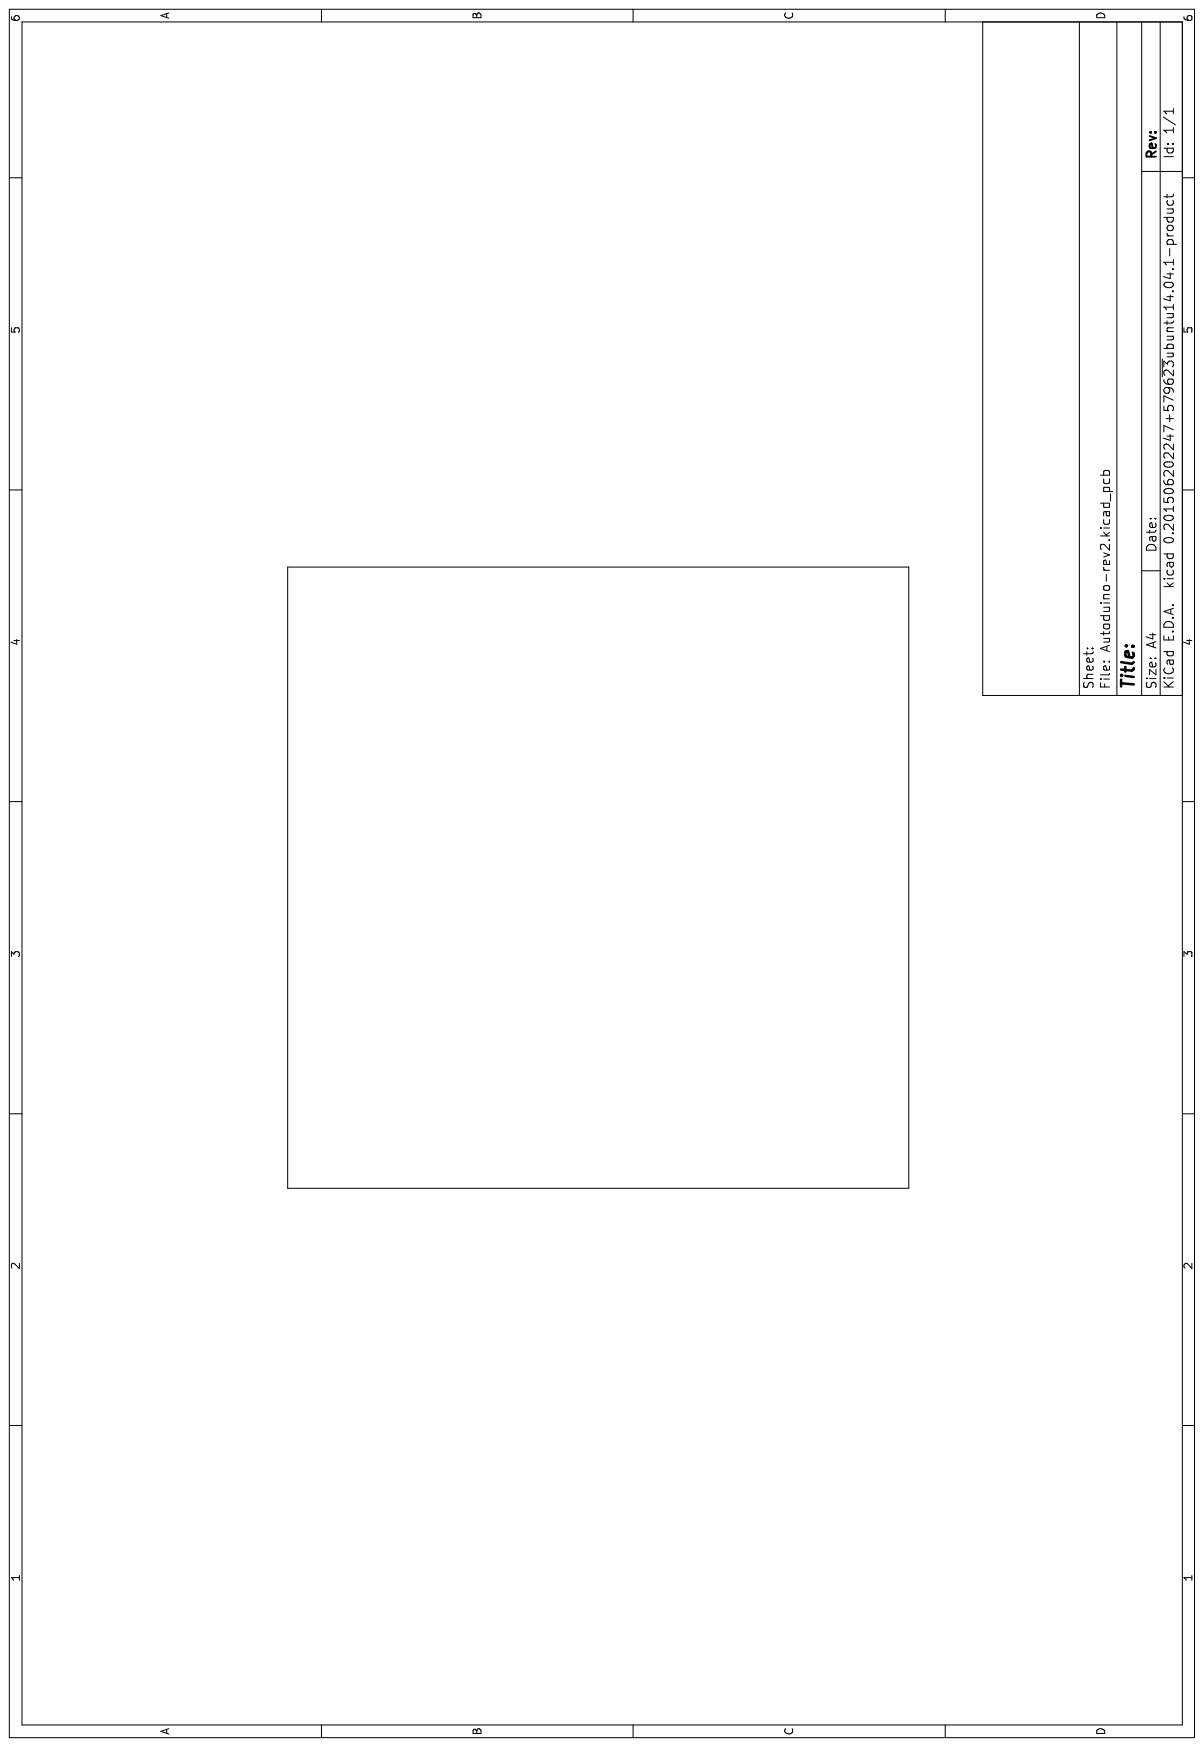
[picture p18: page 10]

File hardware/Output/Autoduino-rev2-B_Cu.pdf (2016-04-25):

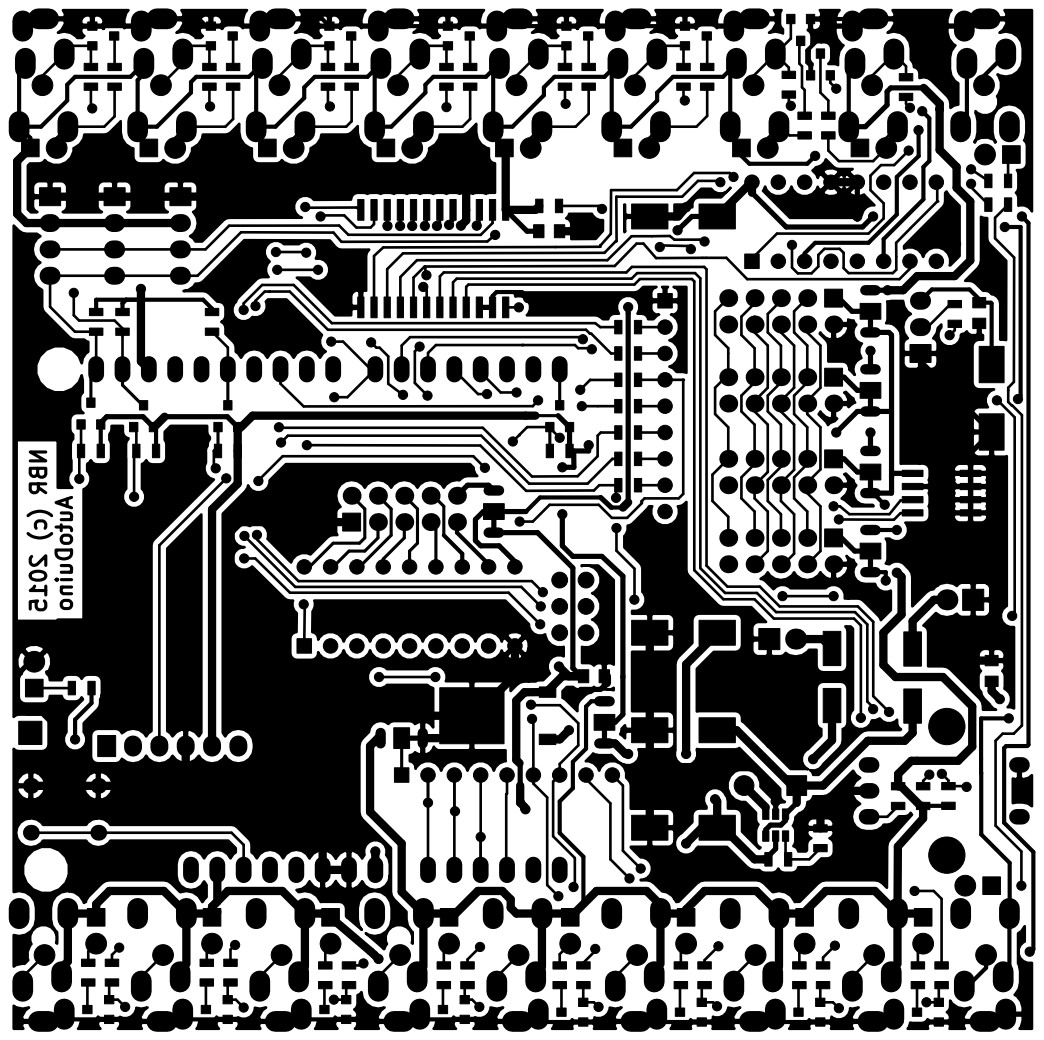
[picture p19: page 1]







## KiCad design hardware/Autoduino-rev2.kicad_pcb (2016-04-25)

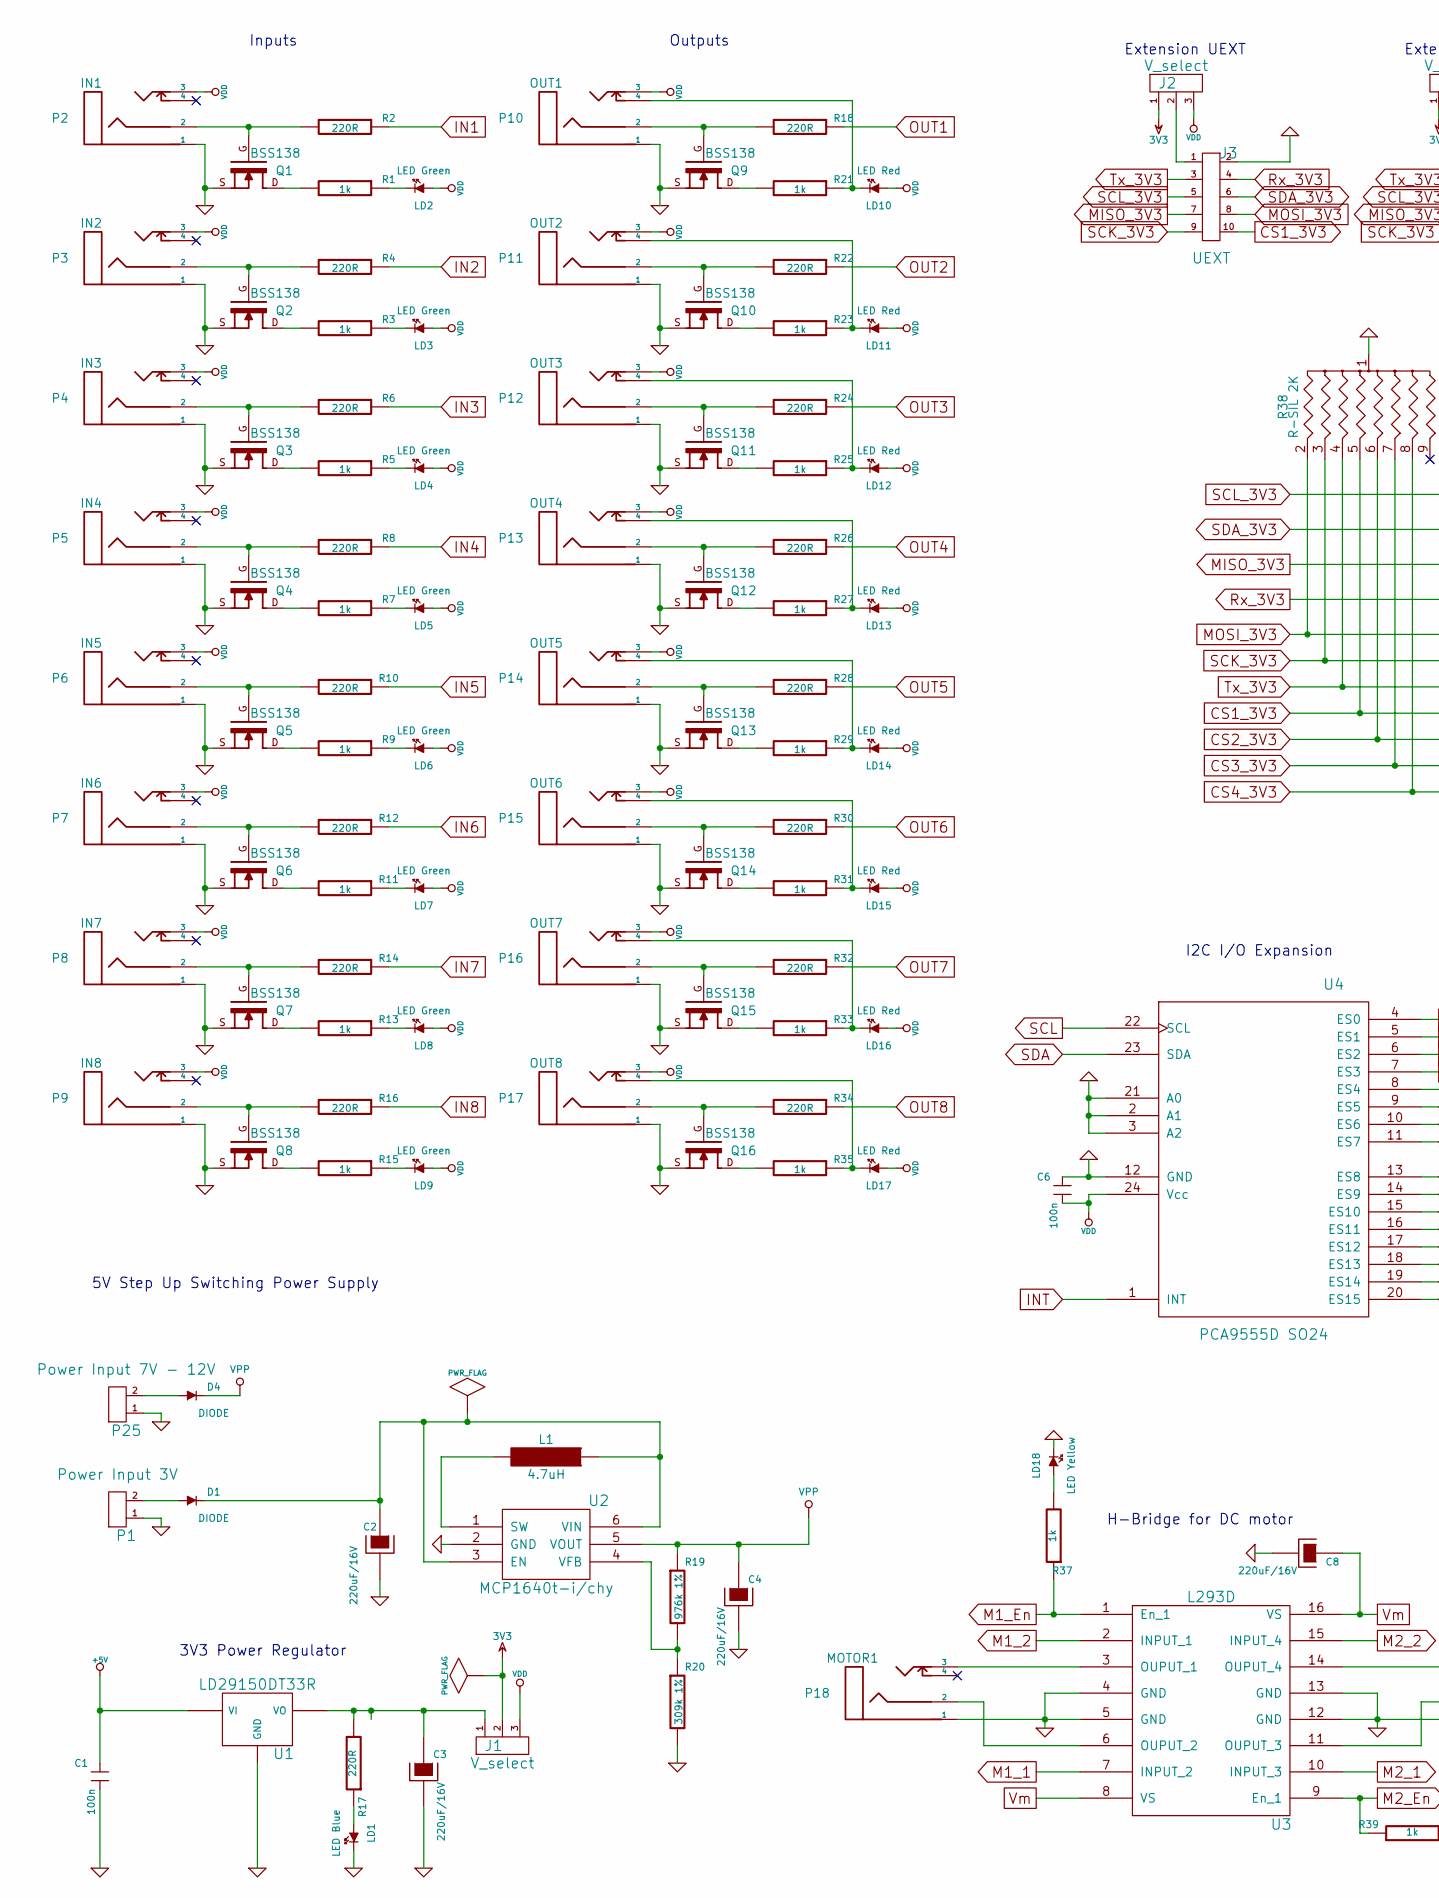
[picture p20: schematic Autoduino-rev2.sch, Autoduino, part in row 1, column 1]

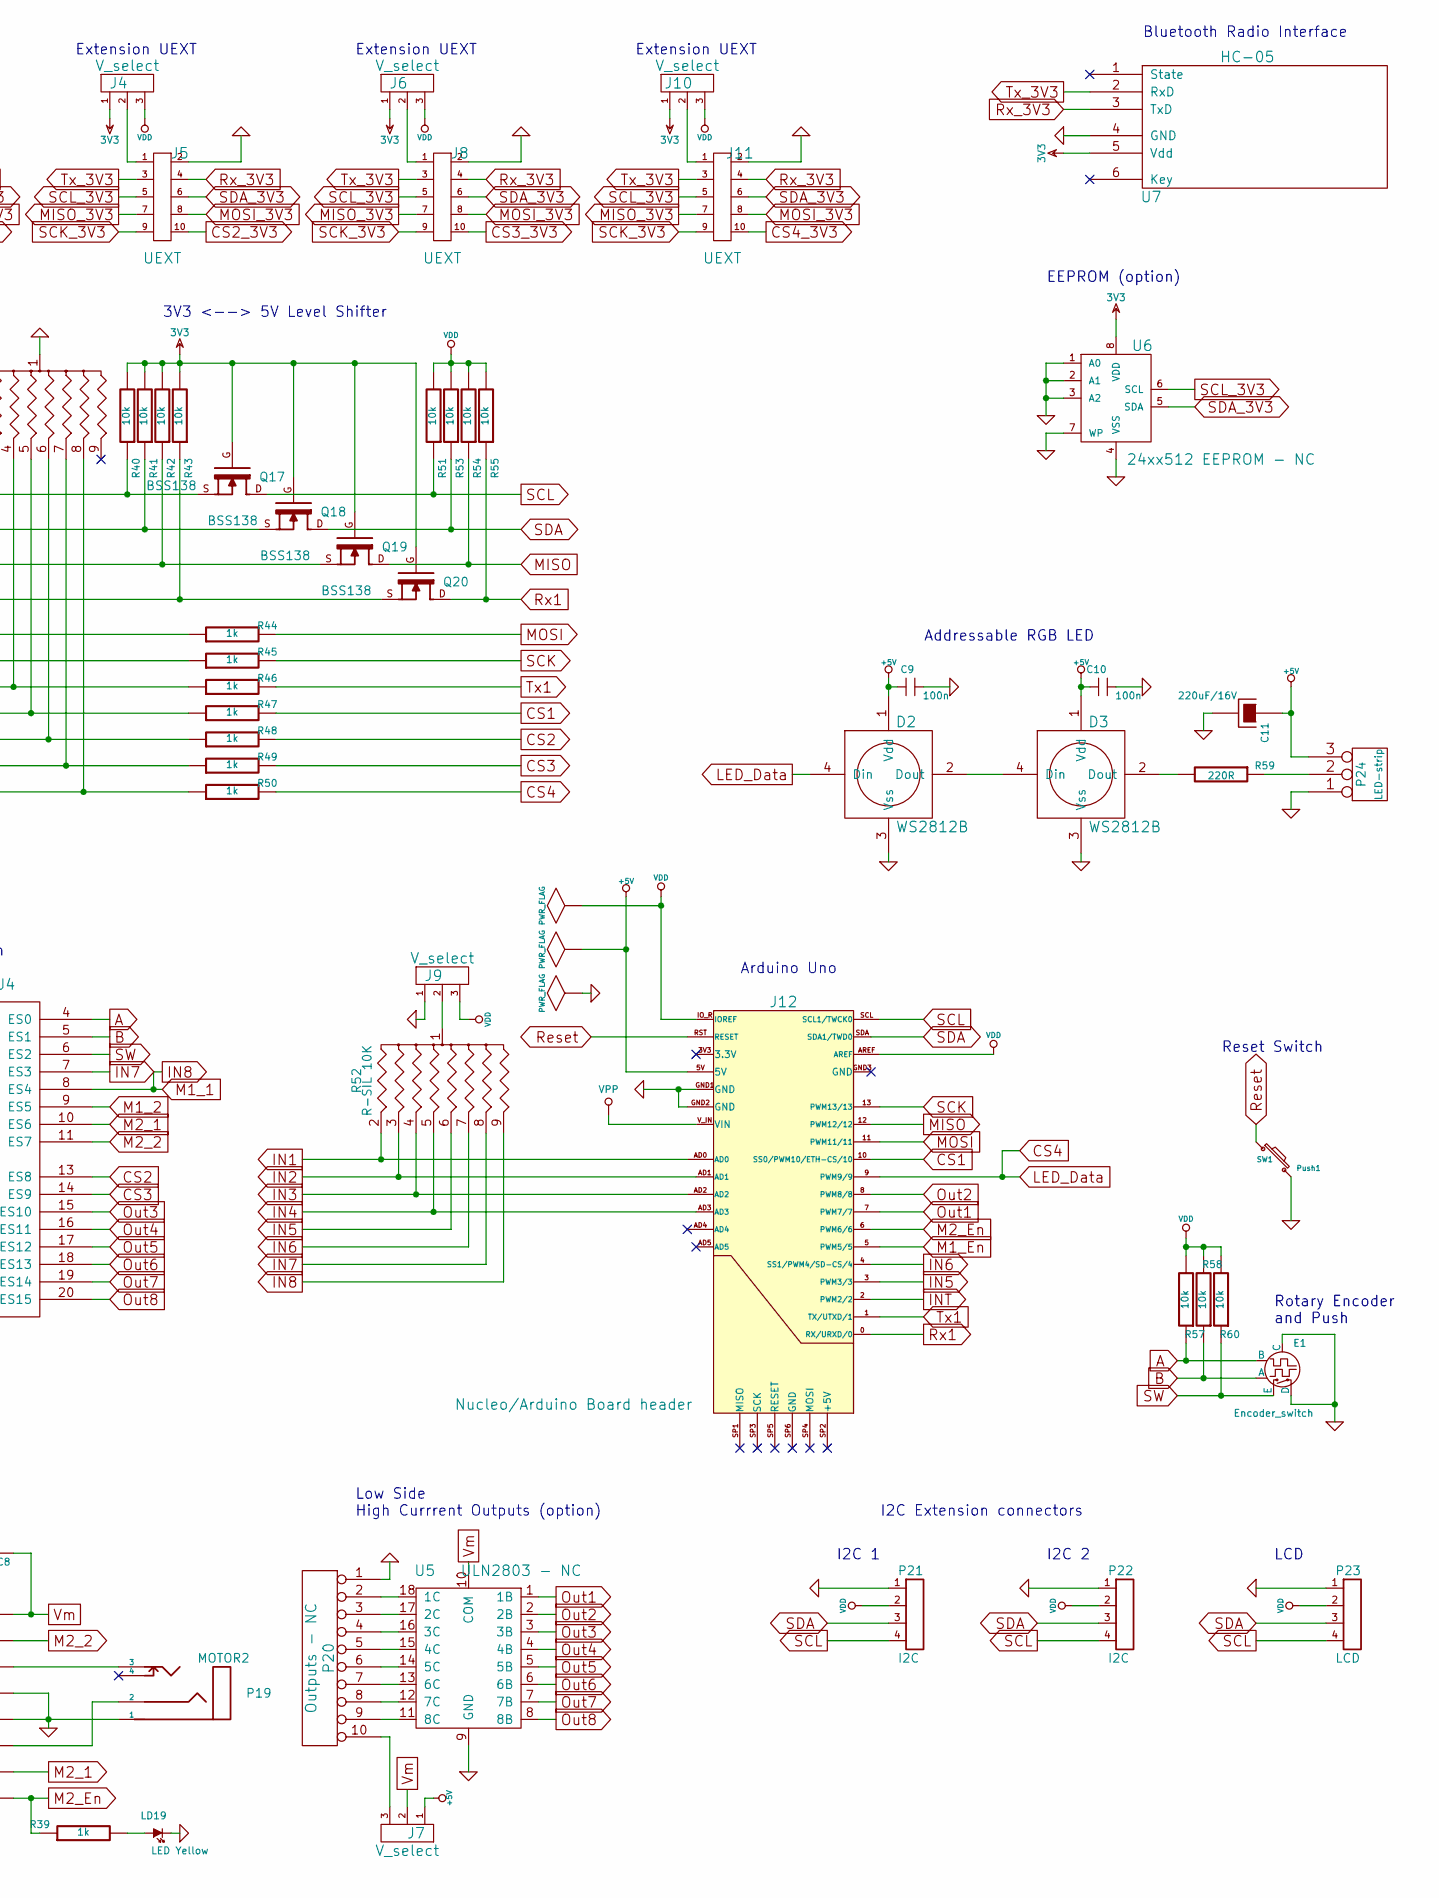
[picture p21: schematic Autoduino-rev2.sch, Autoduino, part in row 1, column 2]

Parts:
C1, C6, C9, C10: 100n; C_0805
C2, C3, C4, C8, C11: 220uF/16V; c_elec_8x10
D1, D4: DIODE; Diode-MiniMELF_Handsoldering
D2, D3: WS2812B
E1: Encoder_switch; encoder_alps-ec12d
J1, J2, J4, J6, J7, J9, J10: V_select; Select
J3, J5, J8, J11: UEXT; Pin_Header_Straight_2x05
J12: Nucleo/Arduino Board header; ARDUINO_SHIELD
L1: 4.7uH; INDUCTOR_V
LD1: LED Blue; LED-3MM
LD2, LD3, LD4, LD5, LD6, LD7, LD8, LD9: LED Green; LED-3MM
LD10, LD11, LD12, LD13, LD14, LD15, LD16, LD17: LED Red; LED-3MM
LD18, LD19: LED Yellow; LED-3MM
P1: Power Input 3V; Pin_Header_Straight_1x02
P2: IN1; PC-208B-Jack2.5_Stereo
P3: IN2; PC-208B-Jack2.5_Stereo
P4: IN3; PC-208B-Jack2.5_Stereo
P5: IN4; PC-208B-Jack2.5_Stereo
P6: IN5; PC-208B-Jack2.5_Stereo
P7: IN6; PC-208B-Jack2.5_Stereo
P8: IN7; PC-208B-Jack2.5_Stereo
P9: IN8; PC-208B-Jack2.5_Stereo
P10: OUT1; PC-208B-Jack2.5_Stereo
P11: OUT2; PC-208B-Jack2.5_Stereo
P12: OUT3; PC-208B-Jack2.5_Stereo
P13: OUT4; PC-208B-Jack2.5_Stereo
P14: OUT5; PC-208B-Jack2.5_Stereo
P15: OUT6; PC-208B-Jack2.5_Stereo
P16: OUT7; PC-208B-Jack2.5_Stereo
P17: OUT8; PC-208B-Jack2.5_Stereo
P18: MOTOR1; PC-208B-Jack2.5_Stereo
P19: MOTOR2; PC-208B-Jack2.5_Stereo
P20: Outputs - NC; Pin_Header_Straight_2x05
P21, P22: I2C; Pin_Header_Straight_1x04
P23: LCD; Pin_Header_Straight_1x04
P24: LED-strip; Pin_Header_Straight_1x03
P25: Power Input 7V - 12V; Pin_Header_Straight_1x02
Q1, Q2, Q3, Q4, Q5, Q6, Q7, Q8, Q9, Q10, Q11, Q12, Q13, Q14, Q15, Q16, Q17, Q18, Q19, Q20: BSS138; SOT23_FET
R1, R3, R5, R7, R9, R11, R13, R15, R21, R23, R25, R27, R29, R31, R33, R35, R37, R39, R44, R45, R46, R47, R48, R49, R50: 1k; R_0805
R2, R4, R6, R8, R10, R12, R14, R16, R17, R18, R22, R24, R26, R28, R30, R32, R34, R59: 220R; R_0805
R19: 976k 1%; R_0805
R20: 309k 1%; R_0805
R38: R-SIL 2K; r_pack8
R40, R41, R42, R43, R51, R53, R54, R55, R57, R58, R60: 10k; R_0805
R52: R-SIL 10K; r_pack8
SW1: Push1; SW_PUSHBUTTON_PTH
U1: LD29150DT33R; DPAK
U2: MCP1640t-i/chy; sot23-6
U3: L293D; DIP-16__300
U4: PCA9555D SO24; SOIC-24_7.5x15.4mm_Pitch1.27mm
U5: ULN2803 - NC; DIP-18__300
U6: 24xx512 EEPROM - NC; so-8
U7: HC-05; Pin_Header_Angled_1x06

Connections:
3V3: J1.2, J2.1, J4.1, J6.1, J10.1, Q17.G, Q18.G, Q19.G, Q20.G, R40.2, R41.2, R42.2, R43.2, U6.8 (VDD), U7.5 (Vdd)
+5V: C1.1, C9.1, C10.1, C11.1, D2.1 (Vdd), D3.1 (Vdd), J7.1, J12.5V, P24.3, U1.1 (VI)
A: E1.3 (B), R57.1, U4.4 (ES0)
B: E1.1 (A), R58.1, U4.5 (ES1)
CS1: J12.10 (SS0/PWM10/ETH-CS/10), R47.2
CS1_3V3: J3.10, R38.5, R47.1
CS2: R48.2, U4.13 (ES8)
CS2_3V3: J5.10, R38.6, R48.1
CS3: R49.2, U4.14 (ES9)
CS3_3V3: J8.10, R38.7, R49.1
CS4_3V3: J11.10, R38.8, R50.1
GND: C1.2, C2.2, C3.2, C4.2, C6.1, C8.2, C9.2, C10.2, C11.2, D2.3 (Vss), D3.3 (Vss), E1.2 (C), E1.5 (D), J3.2, J5.2, J8.2, J9.1, J11.2, J12.GND1 (GND), J12.GND2 (GND), LD1.2 (K), LD18.2 (K), LD19.2 (K), P1.1, P2.1, P3.1, P4.1, P5.1, P6.1, P7.1, P8.1, P9.1, P10.1, P11.1, P12.1, P13.1, P14.1, P15.1, P16.1, P17.1, P18.1, P19.1, P20.1, P21.1, P22.1, P23.1, P24.1, P25.1, Q1.S, Q2.S, Q3.S, Q4.S, Q5.S, Q6.S, Q7.S, Q8.S, Q9.S, Q10.S, Q11.S, Q12.S, Q13.S, Q14.S, Q15.S, Q16.S, R20.2, R38.1, SW1.2, U1.2 (GND), U2.2 (GND), U3.4 (GND), U3.5 (GND), U3.12 (GND), U3.13 (GND), U4.2 (A1), U4.3 (A2), U4.12 (GND), U4.21 (A0), U5.9 (GND), U6.1 (A0), U6.2 (A1), U6.3 (A2), U6.4 (VSS), U6.7 (WP), U7.4 (GND)
IN1: J12.AD0, R2.1, R52.2
IN2: J12.AD1, R4.1, R52.3
IN3: J12.AD2, R6.1, R52.4
IN4: J12.AD3, R8.1, R52.5
IN5: J12.3 (PWM3/3), R10.1, R52.6
IN6: J12.4 (SS1/PWM4/SD-CS/4), R12.1, R52.7
IN7: R14.1, R52.8, U4.7 (ES3)
IN8: R16.1, R52.9, U3.7 (INPUT_2), U4.8 (ES4)
INT: J12.2 (PWM2/2), U4.1 (INT)
LED_Data: D2.4 (Din), J12.9 (PWM9/9), R50.2
M1_2: U3.2 (INPUT_1), U4.9 (ES5)
M1_En: J12.5 (PWM5/5), R37.1, U3.1 (En_1)
M2_1: U3.10 (INPUT_3), U4.10 (ES6)
M2_2: U3.15 (INPUT_4), U4.11 (ES7)
M2_En: J12.6 (PWM6/6), R39.1, U3.9 (En_1)
MISO: J12.12 (PWM12/12), Q19.D, R54.1
MISO_3V3: J3.7, J5.7, J8.7, J11.7, Q19.S, R42.1
MOSI: J12.11 (PWM11/11), R44.2
MOSI_3V3: J3.8, J5.8, J8.8, J11.8, R38.2, R44.1
unnamed: C2.1, D1.2 (K), L1.1, U2.3 (EN), U2.6 (VIN)
unnamed: C3.1, J1.1, R17.2, U1.3 (VO)
unnamed: D1.1 (A), P1.2
unnamed: D2.2 (Dout), D3.4 (Din)
unnamed: D3.2 (Dout), R59.2
unnamed: D4.1 (A), P25.2
unnamed: J2.2, J3.1
unnamed: J4.2, J5.1
unnamed: J6.2, J8.1
unnamed: J7.3, P20.10
unnamed: J9.2, R52.1
unnamed: J10.2, J11.1
unnamed: L1.2, U2.1 (SW)
unnamed: LD1.1 (A), R17.1
unnamed: LD2.2 (K), R1.1
unnamed: LD3.2 (K), R3.1
unnamed: LD4.2 (K), R5.1
unnamed: LD5.2 (K), R7.1
unnamed: LD6.2 (K), R9.1
unnamed: LD7.2 (K), R11.1
unnamed: LD8.2 (K), R13.1
unnamed: LD9.2 (K), R15.1
unnamed: LD10.2 (K), P10.4, R21.1
unnamed: LD11.2 (K), P11.4, R23.1
unnamed: LD12.2 (K), P12.4, R25.1
unnamed: LD13.2 (K), P13.4, R27.1
unnamed: LD14.2 (K), P14.4, R29.1
unnamed: LD15.2 (K), P15.4, R31.1
unnamed: LD16.2 (K), P16.4, R33.1
unnamed: LD17.2 (K), P17.4, R35.1
unnamed: LD18.1 (A), R37.2
unnamed: LD19.1 (A), R39.2
unnamed: P2.2, Q1.G, R2.2
unnamed: P3.2, Q2.G, R4.2
unnamed: P4.2, Q3.G, R6.2
unnamed: P5.2, Q4.G, R8.2
unnamed: P6.2, Q5.G, R10.2
unnamed: P7.2, Q6.G, R12.2
unnamed: P8.2, Q7.G, R14.2
unnamed: P9.2, Q8.G, R16.2
unnamed: P10.2, Q9.G, R18.2
unnamed: P11.2, Q10.G, R22.2
unnamed: P12.2, Q11.G, R24.2
unnamed: P13.2, Q12.G, R26.2
unnamed: P14.2, Q13.G, R28.2
unnamed: P15.2, Q14.G, R30.2
unnamed: P16.2, Q15.G, R32.2
unnamed: P17.2, Q16.G, R34.2
unnamed: P18.2, U3.6 (OUPUT_2)
unnamed: P18.3, U3.3 (OUPUT_1)
unnamed: P19.2, U3.11 (OUPUT_3)
unnamed: P19.3, U3.14 (OUPUT_4)
unnamed: P20.2, U5.18 (1C)
unnamed: P20.3, U5.17 (2C)
unnamed: P20.4, U5.16 (3C)
unnamed: P20.5, U5.15 (4C)
unnamed: P20.6, U5.14 (5C)
unnamed: P20.7, U5.13 (6C)
unnamed: P20.8, U5.12 (7C)
unnamed: P20.9, U5.11 (8C)
unnamed: P24.2 (PM), R59.1
unnamed: Q1.D, R1.2
unnamed: Q2.D, R3.2
unnamed: Q3.D, R5.2
unnamed: Q4.D, R7.2
unnamed: Q5.D, R9.2
unnamed: Q6.D, R11.2
unnamed: Q7.D, R13.2
unnamed: Q8.D, R15.2
unnamed: Q9.D, R21.2
unnamed: Q10.D, R23.2
unnamed: Q11.D, R25.2
unnamed: Q12.D, R27.2
unnamed: Q13.D, R29.2
unnamed: Q14.D, R31.2
unnamed: Q15.D, R33.2
unnamed: Q16.D, R35.2
unnamed: R19.2, R20.1, U2.4 (VFB)
OUT1: J12.7 (PWM7/7), R18.1, U5.1 (1B)
OUT2: J12.8 (PWM8/8), R22.1, U5.2 (2B)
OUT4: R26.1, U4.16 (ES11), U5.4 (4B)
OUT5: R28.1, U4.17 (ES12), U5.5 (5B)
OUT7: R32.1, U4.19 (ES14), U5.7 (7B)
OUT8: R34.1, U4.20 (ES15), U5.8 (8B)
Out3: R24.1, U4.15 (ES10), U5.3 (3B)
Out6: R30.1, U4.18 (ES13), U5.6 (6B)
Reset: J12.RST (RESET), SW1.1
Rx1: J12.0 (RX/URXD/0), Q20.D, R55.1
Rx_3V3: J3.4, J5.4, J8.4, J11.4, Q20.S, R43.1, U7.3 (TxD)
SCK: J12.13 (PWM13/13), R45.2
SCK_3V3: J3.9, J5.9, J8.9, J11.9, R38.3, R45.1
SCL: J12.SCL (SCL1/TWCK0), P21.4, P22.4, P23.4, Q17.D, R51.1, U4.22 (SCL)
SCL_3V3: J3.5, J5.5, J8.5, J11.5, Q17.S, R40.1, U6.6 (SCL)
SDA: J12.SDA (SDA1/TWD0), P21.3, P22.3, P23.3, Q18.D, R53.1, U4.23 (SDA)
SDA_3V3: J3.6, J5.6, J8.6, J11.6, Q18.S, R41.1, U6.5 (SDA)
SW: E1.4 (E), R60.1, U4.6 (ES2)
Tx1: J12.1 (TX/UTXD/1), R46.2
Tx_3V3: J3.3, J5.3, J8.3, J11.3, R38.4, R46.1, U7.2 (RxD)
VDD: C6.2, J1.3, J2.3, J4.3, J6.3, J9.3, J10.3, J12.AREF, J12.IO_R (IOREF), LD2.1 (A), LD3.1 (A), LD4.1 (A), LD5.1 (A), LD6.1 (A), LD7.1 (A), LD8.1 (A), LD9.1 (A), LD10.1 (A), LD11.1 (A), LD12.1 (A), LD13.1 (A), LD14.1 (A), LD15.1 (A), LD16.1 (A), LD17.1 (A), P2.3, P3.3, P4.3, P5.3, P6.3, P7.3, P8.3, P9.3, P10.3, P11.3, P12.3, P13.3, P14.3, P15.3, P16.3, P17.3, P21.2, P22.2, P23.2, R51.2, R53.2, R54.2, R55.2, R57.2, R58.2, R60.2, U4.24 (Vcc)
VPP: C4.1, D4.2 (K), J12.V_IN (VIN), R19.1, U2.5 (VOUT)
Vm: C8.1, J7.2, U3.8 (VS), U3.16 (VS), U5.10 (COM)

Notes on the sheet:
Extension UEXT
EEPROM (option)
5V Step Up Switching Power Supply
3V3 Power Regulator
Bluetooth Radio Interface
Low Side High Currrent Outputs (option)
3V3 <--> 5V Level Shifter
Addressable RGB LED
Arduino Uno
I2C I/O Expansion
H-Bridge for DC motor
LCD
Rotary Encoder and Push
Reset Switch
Inputs
Outputs
I2C Extension connectors
I2C 2
I2C 1

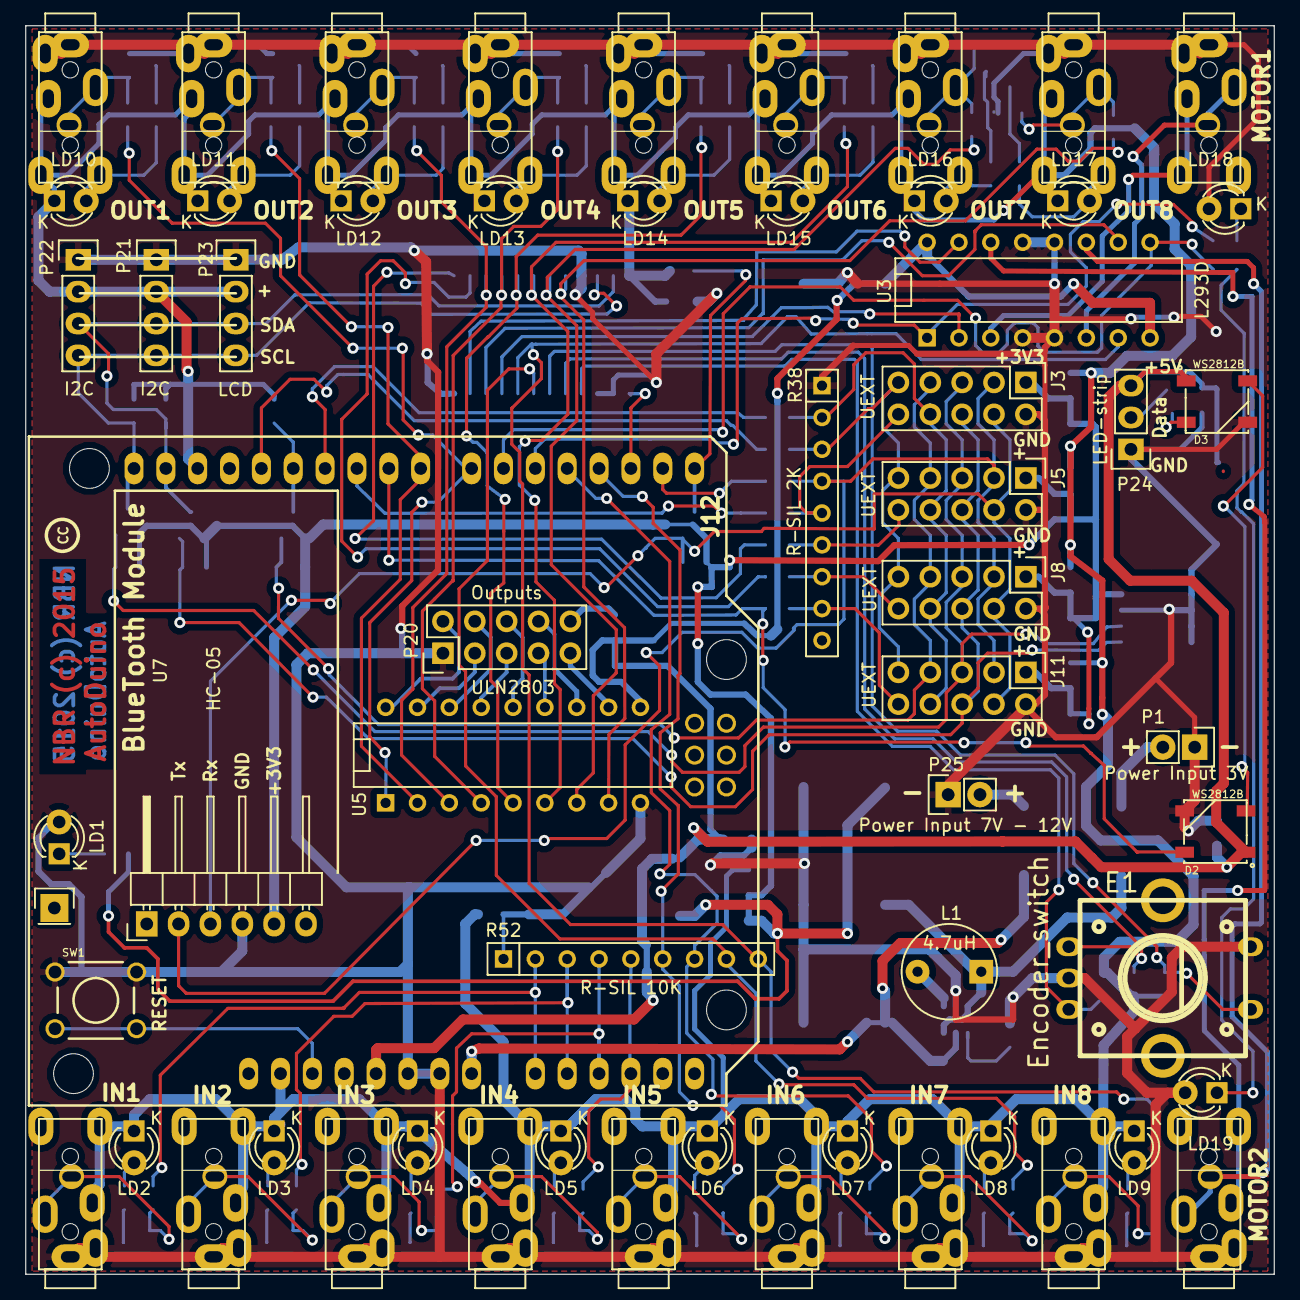
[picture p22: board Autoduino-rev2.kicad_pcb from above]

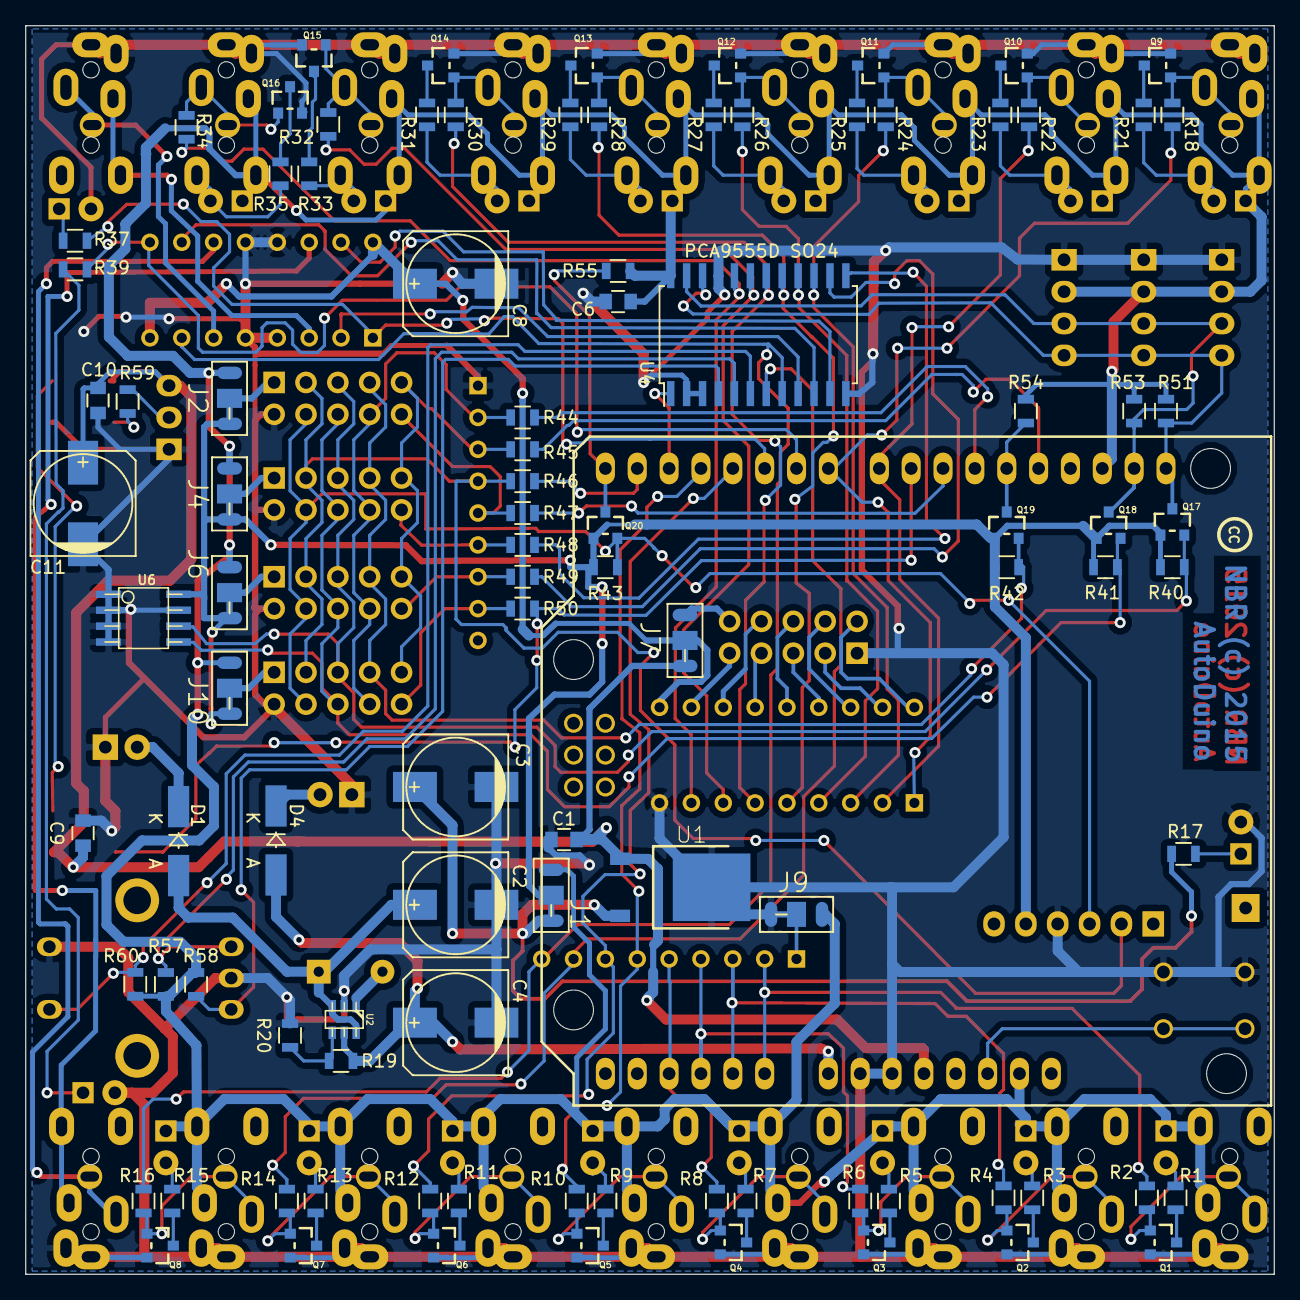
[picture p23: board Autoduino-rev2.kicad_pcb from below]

Board: 2 copper layers, 99.6 x 99.6 mm, 160 parts (99 on the bottom side), 132 nets.

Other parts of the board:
LOGO_CC: VAL**; LOGO_CC_2.8mm
LOGO_CC#2: VAL**; LOGO_CC_2.8mm
P0: Pin_Header_Straight_1x01

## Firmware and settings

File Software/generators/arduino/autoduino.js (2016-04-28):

//Code generator functions for the AUTODUINO interface

/**
 * @license
 * GPL
 *
 * Copyright 2016 Bernard Remond.
 * https://github.com/nbremond77
 *
 */

/**
 * @fileoverview Helper functions for generating autoduino interface board.
 * @author nbremond@laposte.net (Bernard Remond)
 */

/**
 * @fileoverview Helper functions for generating seeeduino autoduino blocks.
 * @author gasolin@gmail.com (Fred Lin)
 */

//---------------------------------------------------


myLibrary_gpio_expander = "#include <Wire.h>\n\
#include <stdio.h>\n\
#include <inttypes.h>\n\
#include <Arduino.h>\n\
\n\
class gpio_expander {\n\
public:\n\
  gpio_expander( );\n\
  virtual void  begin(bool protocolInitOverride=false) = 0;\n\
protected:\n\
  inline uint16_t   byte2word(byte high_byte,byte low_byte){return (word)high_byte << 8 | (word)low_byte;};\n\
  inline byte     word2highByte(uint16_t data){return (byte)(data >> 8);};\n\
  inline byte     word2lowByte(uint16_t data){return (byte)(data & 0x00FF);};\n\
private:\n\
};\n\
\n\
\n\
class pca9555 : public gpio_expander\n\
{\n\
public:\n\
  pca9555(const uint8_t adrs);\n\
  pca9555();;//used with other libraries only\n\
  void      postSetup(const uint8_t adrs);//used with other libraries only\n\
  virtual void  begin(bool protocolInitOverride=false); //protocolInitOverride=true will not init the SPI \n\
  void      gpioPinMode(uint16_t mode);         //OUTPUT=all out,INPUT=all in,0xxxx=you choose\n\
  void      gpioPinMode(uint8_t pin, bool mode);    //set a unique pin as IN(1) or OUT (0)\n\
  void      gpioPort(uint16_t value);         //HIGH=all Hi, LOW=all Low,0xxxx=you choose witch low or hi\n\
  void      gpioPort(byte lowByte, byte highByte);    //same as abowe but uses 2 separate bytes\n\
  uint16_t    readGpioPort();               //read the state of the pins (all)\n\
  uint16_t    readGpioPortFast();             \n\
  void      gpioDigitalWrite(uint8_t pin, bool value);  //write data to one pin\n\
  void      gpioDigitalWriteFast(uint8_t pin, bool value);\n\
  int       gpioDigitalRead(uint8_t pin);       //read data from one pin\n\
  uint8_t     gpioRegisterReadByte(byte reg);         //read a byte from chip register\n\
  int       gpioDigitalReadFast(uint8_t pin);\n\
  void      gpioRegisterWriteByte(byte reg,byte data);    //write a byte in a chip register\n\
  void      gpioRegisterWriteWord(byte reg,word data);    //write a word in a chip register\n\
  void      portPullup(uint16_t data);            // HIGH=all pullup, LOW=all pulldown,0xxxx=you choose witch\n\
  void      gpioPortUpdate();\n\
  // direct access commands\n\
  uint16_t    readAddress(byte addr);\n\
  //------------------------- REGISTERS\n\
  byte      IODIR;//GPCONF\n\
  byte      GPPU;//GPO\n\
  byte      GPIO;//GPI\n\
  byte      IPOL;//GPPOL\n\
private:\n\
  uint8_t     _adrs;\n\
  uint16_t    _gpioDirection;\n\
  uint16_t    _gpioState;\n\
  bool      _error;\n\
  void      writeByte(byte addr, byte data);  \n\
  void      writeWord(byte addr, uint16_t data);\n\
};\n\
\n\
gpio_expander::gpio_expander() \n\
{\n\
}\n\
\n\
\n\
pca9555::pca9555(){\n\
}\n\
\n\
pca9555::pca9555(const uint8_t adrs){\n\
  postSetup(adrs);\n\
}\n\
\n\
void pca9555::postSetup(const uint8_t adrs){\n\
  if (adrs >= 0x20 && adrs <= 0x27){//basic addressing\n\
    _adrs = adrs;\n\
    _error = false;\n\
  } else if (adrs >= 0x28 && adrs <= 0xDE){//advanced addressing\n\
    //todo\n\
    _error = false;\n\
  } else {\n\
    _error = true;\n\
  }\n\
  //setup register values for this chip\n\
  IODIR =   0x06;//Configuration Registers (0x06..0x07)\n\
  GPPU =    0x02;//Output Port Registers (0x02..0x03)\n\
  GPIO =    0x00;//Input Port Registers (0x00..0x01)\n\
  IPOL =    0x04;//Polarity Inversion Registers (0x04..0x05)(\n\
}\n\
\n\
void pca9555::begin(bool protocolInitOverride) {\n\
  if (!protocolInitOverride && !_error){\n\
    Wire.begin();\n\
    #if ARDUINO >= 157\n\
      Wire.setClock(400000UL); // Set I2C frequency to 400kHz\n\
    #else\n\
      TWBR = ((F_CPU / 400000UL) - 16) / 2; // Set I2C frequency to 400kHz\n\
    #endif\n\
  }\n\
  delay(100);\n\
  _gpioDirection = 0xFFFF;//all in\n\
  _gpioState = 0x0000;//all low \n\
}\n\
\n\
\n\
\n\
\n\
uint16_t pca9555::readAddress(byte addr){\n\
  byte low_byte = 0;\n\
  byte high_byte = 0;\n\
  if (!_error){\n\
    Wire.beginTransmission(_adrs);\n\
    Wire.write(addr);//witch register?\n\
    //Wire.endTransmission();\n\
    Wire.endTransmission(false);// looks like in this way it works!\n\
    Wire.requestFrom((uint8_t)_adrs,(uint8_t)2);\n\
    low_byte = Wire.read();\n\
    high_byte = Wire.read();\n\
  } \n\
  return byte2word(high_byte,low_byte);\n\
}\n\
\n\
\n\
\n\
void pca9555::gpioPinMode(uint16_t mode){\n\
  if (mode == INPUT){\n\
    _gpioDirection = 0xFFFF;\n\
  } else if (mode == OUTPUT){ \n\
    _gpioDirection = 0x0000;\n\
    _gpioState = 0x0000;\n\
  } else {\n\
    _gpioDirection = mode;\n\
  }\n\
  writeWord(IODIR,_gpioDirection);\n\
}\n\
\n\
void pca9555::gpioPinMode(uint8_t pin, bool mode){\n\
  if (pin < 16){//0...15\n\
    mode == INPUT ? _gpioDirection |= (1 << pin) :_gpioDirection &= ~(1 << pin);\n\
    writeWord(IODIR,_gpioDirection);\n\
  }\n\
}\n\
\n\
void pca9555::gpioPort(uint16_t value){\n\
  if (value == HIGH){\n\
    _gpioState = 0xFFFF;\n\
  } else if (value == LOW){ \n\
    _gpioState = 0x0000;\n\
  } else {\n\
    _gpioState = value;\n\
  }\n\
  writeWord(GPIO,_gpioState);\n\
}\n\
\n\
void pca9555::gpioPort(byte lowByte, byte highByte){\n\
  _gpioState = byte2word(highByte,lowByte);\n\
  writeWord(GPIO,_gpioState);\n\
}\n\
\n\
\n\
uint16_t pca9555::readGpioPort(){\n\
  return readAddress(GPIO);\n\
}\n\
\n\
uint16_t pca9555::readGpioPortFast(){\n\
  return _gpioState;\n\
}\n\
\n\
int pca9555::gpioDigitalReadFast(uint8_t pin){\n\
  int temp = 0;\n\
  if (pin < 16) temp = bitRead(_gpioState,pin);\n\
  return temp;\n\
}\n\
\n\
\n\
\n\
\n\
void pca9555::gpioDigitalWrite(uint8_t pin, bool value){\n\
  if (pin < 16){//0...15\n\
    value == HIGH ? _gpioState |= (1 << pin) : _gpioState &= ~(1 << pin);\n\
    writeWord(GPPU,_gpioState);\n\
  }\n\
}\n\
\n\
void pca9555::gpioDigitalWriteFast(uint8_t pin, bool value){\n\
  if (pin < 16){//0...15\n\
    value == HIGH ? _gpioState |= (1 << pin) : _gpioState &= ~(1 << pin);\n\
  }\n\
}\n\
\n\
void pca9555::gpioPortUpdate(){\n\
  writeWord(GPIO,_gpioState);\n\
}\n\
\n\
int pca9555::gpioDigitalRead(uint8_t pin){\n\
  if (pin < 16) return (int)(readAddress(GPIO) & 1 << pin);\n\
  return 0;\n\
}\n\
\n\
uint8_t pca9555::gpioRegisterReadByte(byte reg){\n\
  uint8_t data = 0;\n\
  if (!_error){\n\
    Wire.beginTransmission(_adrs);\n\
    Wire.write(reg);\n\
    Wire.endTransmission();\n\
    Wire.requestFrom((uint8_t)_adrs,(uint8_t)1);\n\
    data = Wire.read();\n\
  }\n\
  return data;\n\
}\n\
\n\
\n\
void pca9555::gpioRegisterWriteByte(byte reg,byte data){\n\
  writeByte(reg,(byte)data);\n\
}\n\
\n\
void pca9555::gpioRegisterWriteWord(byte reg,word data){\n\
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

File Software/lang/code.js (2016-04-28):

/**
 * Based on 
 * 
 * Blockly Demos: Code
 *
 * Copyright 2012 Google Inc.
 * https://developers.google.com/blockly/
 *
 * Licensed under the Apache License, Version 2.0 (the "License");
 * you may not use this file except in compliance with the License.
 * You may obtain a copy of the License at
 *
 *   http://www.apache.org/licenses/LICENSE-2.0
 *
 * Unless required by applicable law or agreed to in writing, software
 * distributed under the License is distributed on an "AS IS" BASIS,
 * WITHOUT WARRANTIES OR CONDITIONS OF ANY KIND, either express or implied.
 * See the License for the specific language governing permissions and
 * limitations under the License.
 */

/**
 * @fileoverview JavaScript for Blockly's Code demo.
 * @author fraser@google.com (Neil Fraser)
 */
'use strict';

/**
 * Create a namespace for the application.
 */
var Code = {};

/**
 * Lookup for names of supported languages.  Keys should be in ISO 639 format.
 */
Code.LANGUAGE_NAME = {
		  'ar': 'العربية',
		  'be-tarask': 'Taraškievica',
		  'br': 'Brezhoneg',
		  'ca': 'Català',
		  'cs': 'Česky',
		  'da': 'Dansk',
		  'de': 'Deutsch',
		  'el': 'Ελληνικά',
		  'en': 'English',
		  'es': 'Español',
		  'fa': 'فارسی',
		  'fr': 'Français',
		  'he': 'עברית',
		  'hrx': 'Hunsrik',
		  'hu': 'Magyar',
		  'ia': 'Interlingua',
		  'is': 'Íslenska',
		  'it': 'Italiano',
		  'ja': '日本語',
		  'ko': '한국어',
		  'mk': 'Македонски',
		  'ms': 'Bahasa Melayu',
		  'nb': 'Norsk Bokmål',
		  'nl': 'Nederlands, Vlaams',
		  'oc': 'Lenga d\'òc',
		  'pl': 'Polski',
		  'pms': 'Piemontèis',
		  'pt-br': 'Português Brasileiro',
		  'ro': 'Română',
		  'ru': 'Русский',
		  'sc': 'Sardu',
		  'sk': 'Slovenčina',
		  'sr': 'Српски',
		  'sv': 'Svenska',
		  'ta': 'தமிழ்',
		  'th': 'ภาษาไทย',
		  'tlh': 'tlhIngan Hol',
		  'tr': 'Türkçe',
		  'uk': 'Українська',
		  'vi': 'Tiếng Việt',
		  'zh-hans': '簡體中文',
		  'zh-hant': '正體中文'
		};

/**
 * List of RTL languages.
 */
Code.LANGUAGE_RTL = ['ar', 'fa', 'he'];

/**
 * Get the language of this user from the URL.
 * @return {string} User's language.
 */
Code.getLang = function() {
  var lang = BlocklyDuino.getStringParamFromUrl('lang', '');
  if (Code.LANGUAGE_NAME[lang] === undefined) {
    // Default to English.
    lang = 'fr';
  }
  return lang;
};

/**
 * Is the current language (Code.LANG) an RTL language?
 * @return {boolean} True if RTL, false if LTR.
 */
Code.isRtl = function() {
  return Code.LANGUAGE_RTL.indexOf(Code.LANG) != -1;
};

/**
 * Save the blocks and reload with a different language.
 */
Code.changeLanguage = function() {
  // Store the blocks for the duration of the reload.
	BlocklyDuino.backupBlocks();

  var languageMenuSelected = $('#languageMenu option:selected').val();
  var newLang = encodeURIComponent(languageMenuSelected);
  var search = window.location.search;
  if (search.length <= 1) {
    search = '?lang=' + newLang;
  } else if (search.match(/[?&]lang=[^&]*/)) {
    search = search.replace(/([?&]lang=)[^&]*/, '$1' + newLang);
  } else {
    search = search.replace(/\?/, '?lang=' + newLang + '&');
  }

  window.location = window.location.protocol + '//' +
      window.location.host + window.location.pathname + search;
};

/**
 * User's language (e.g. "en").
 * @type string
 */
Code.LANG = Code.getLang();

/**
 * Initialize the page language.
 */
Code.initLanguage = function() {
  // Set the HTML's language and direction.
  var rtl = Code.isRtl();
  $("html").attr('dir', rtl ? 'rtl' : 'ltr');
  $("html").attr('lang', Code.LANG);

  // Sort languages alphabetically.
  var languages = [];
  for (var lang in Code.LANGUAGE_NAME) {
    languages.push([Code.LANGUAGE_NAME[lang], lang]);
  }
  var comp = function(a, b) {
    // Sort based on first argument ('English', 'Русский', '简体字', etc).
    if (a[0] > b[0]) return 1;
    if (a[0] < b[0]) return -1;
    return 0;
  };
  languages.sort(comp);

// Populate the language selection menu.
  var languageMenu = $('#languageMenu');
  languageMenu.empty();
  for (var i = 0; i < languages.length; i++) {
    var tuple = languages[i];
    var lang = tuple[tuple.length - 1];
    var option = new Option(tuple[0], lang);
    if (lang == Code.LANG) {
      option.selected = true;
    }
    languageMenu.append(option);
  }
  languageMenu.bind('change', Code.changeLanguage);

  // Inject language strings.
  $('#title').text(MSG['title']);
  $('#span_about').text(MSG['span_about']);
  $('#span_example').text(MSG['span_example']);
  $('#span_create_example').text(MSG['span_create_example']);
  $('#span_picture').text(MSG['span_picture']);
  $('#aboutModalLabel').text(MSG['aboutModalLabel']);
  $('#aboutBody').html(MSG['aboutBody']);
  
  $('#btn_switch').attr('title', MSG['btn_switch']);

  $('#span_config').text(MSG['span_config']);
  $('#labelArduinoCard').text(MSG['labelArduinoCard']);

  $('#btn_preview').attr('title', MSG['btn_preview']);

  $('#btn_inline').attr('title', MSG['btn_inline']);

  $('#span_delete').text(MSG['span_delete']);
  $('#span_saveXML').text(MSG['span_saveXML']);
  $('#span_fakeload').text(MSG['span_fakeload']);

  $('#a_maquette').text(MSG['span_maquette']);
  $('#a_supervision').text(MSG['span_supervision']);
  $('#a_blocks').text(MSG['a_blocks']);
  $('#a_arduino').text(MSG['a_arduino']);
  $('#a_term').text(MSG['a_term']);
  $('#a_xml').text(MSG['a_xml']);
  
  $('#span_plugin_codebender').text(MSG['span_plugin_codebender']);
  $('#span_verify_codebender').text(MSG['span_verify_codebender']);
  $('#span_flash_codebender').text(MSG['span_flash_codebender']);
  $('#span_saveIno').text(MSG['span_saveIno']);
  $('#span_pasteIDEArduino').text(MSG['span_pasteIDEArduino']);
  $('#span_connect_serial').text(MSG['span_connect_serial']);
  $('#span_edit_code').text(MSG['span_edit_code']);

  $('#configModalLabel').text(MSG['configModalLabel']);
  $('#span_select_all').text(MSG['span_select_all']);
  $('#span_put_in_url').text(MSG['span_put_in_url']);
  $('#btn_close_config').text(MSG['btn_close']);
  $('#btn_valid_config').text(MSG['btn_valid']);
  $('#btn_close_msg').text(MSG['btn_close']);
  $('#btn_valid_msg').text(MSG['btn_valid']);

  $('#editModalLabel').text(MSG['editModalLabel']);
  $('#showcardLabel').text(MSG['showcardLabel']);
  $('#exampleModalLabel').text(MSG['exampleModalLabel']);
  
  $('#btn_doc').attr('title', MSG['span_doc']);  
  $('#btn_tuto').attr('title', MSG['span_tuto']);
  $('#btn_closeCode').text(MSG['btn_closeCode']);
  $('#btn_validCode').text(MSG['btn_validCode']);

  $('#msg_ajax_ko').text(MSG['msg_ajax_ko']);
  $('#span_ajax_msg').text(MSG['span_ajax_msg']);
  
  $("xml").find("category").each(function() {
	// add attribute ID to keep categorie code
	$(this).attr('id', $(this).attr('name'));
	$(this).attr('name', Blockly.Msg[$(this).attr('name')]);
  });

};
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

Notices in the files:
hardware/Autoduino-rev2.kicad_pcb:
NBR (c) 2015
